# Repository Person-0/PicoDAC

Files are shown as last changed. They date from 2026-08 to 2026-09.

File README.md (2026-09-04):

# **PicoDAC**

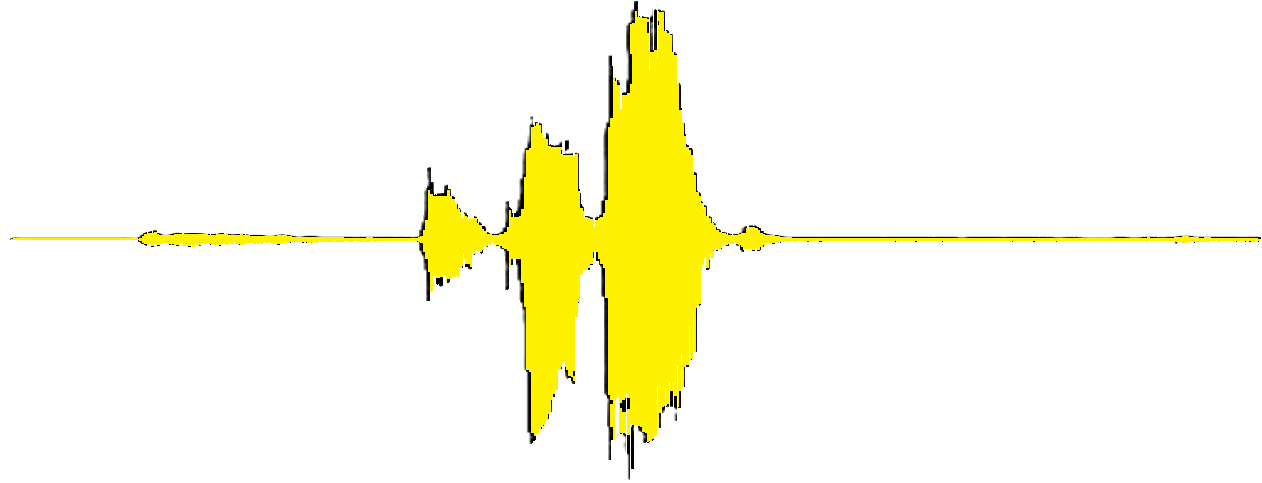
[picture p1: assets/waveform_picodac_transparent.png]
<br>

*USB-C to 3.5mm HiFi mini DAC*

Fully custom PCB and 3D printed case.

## Design

### Preview Images
Note that a specially cut transparent acrylic sheet will be used as the top lid of the main PCB case which will be superglued to part of the case that is non-detachable.

The main PCB case also requires [this 2.5X8 screw](https://sharvielectronics.com/product/m2-5x8mm-phillips-head-mounting-screw-stainless-steel/) that will be used to attach the detachable part with the non-detachable part.

As for the case of the board - 2, since it really is just two directly connected USB-C plugs, the top and bottom part of the case will be glued together after seating the board-2 PCB inside it properly (after testing it).

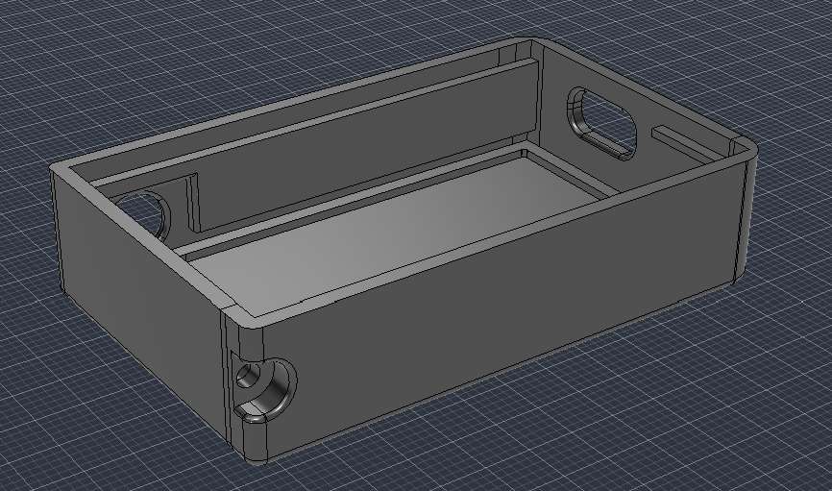
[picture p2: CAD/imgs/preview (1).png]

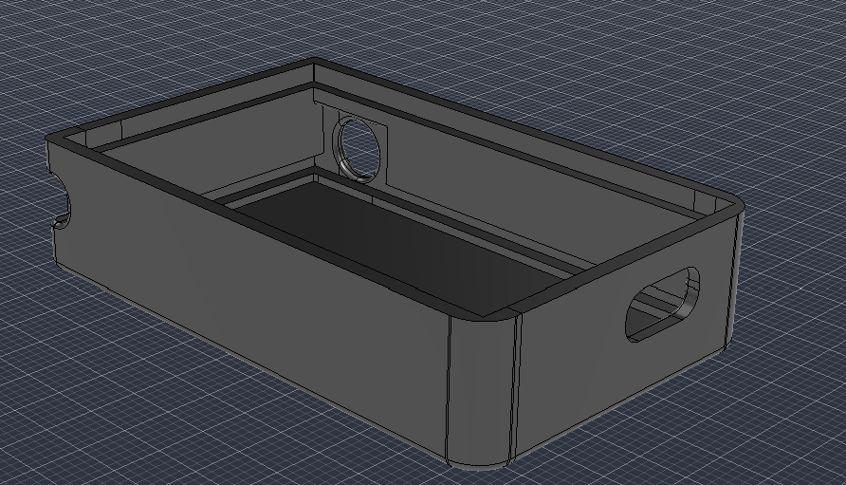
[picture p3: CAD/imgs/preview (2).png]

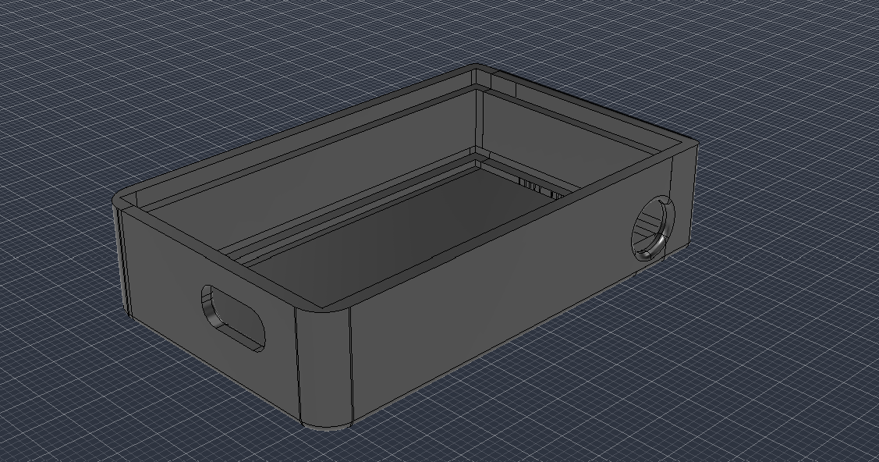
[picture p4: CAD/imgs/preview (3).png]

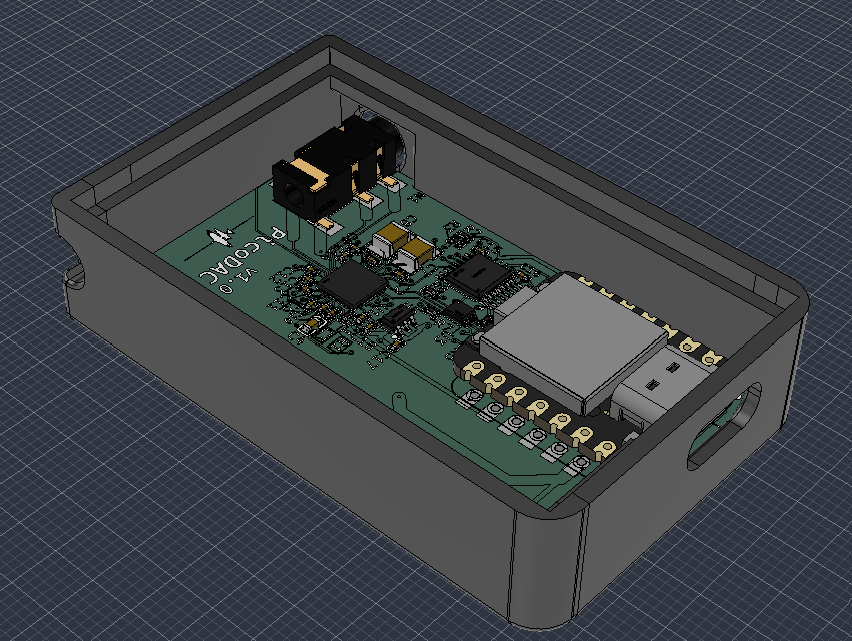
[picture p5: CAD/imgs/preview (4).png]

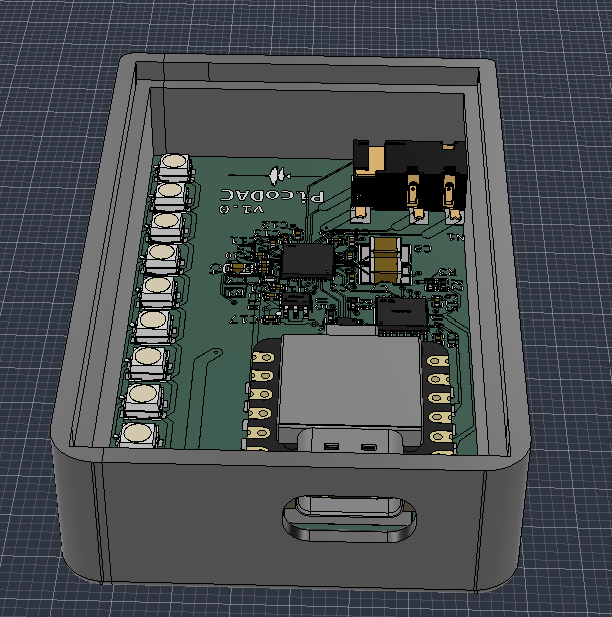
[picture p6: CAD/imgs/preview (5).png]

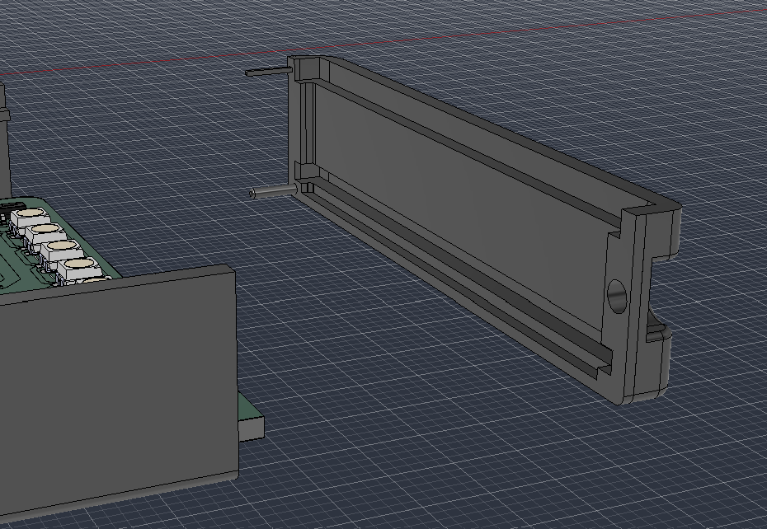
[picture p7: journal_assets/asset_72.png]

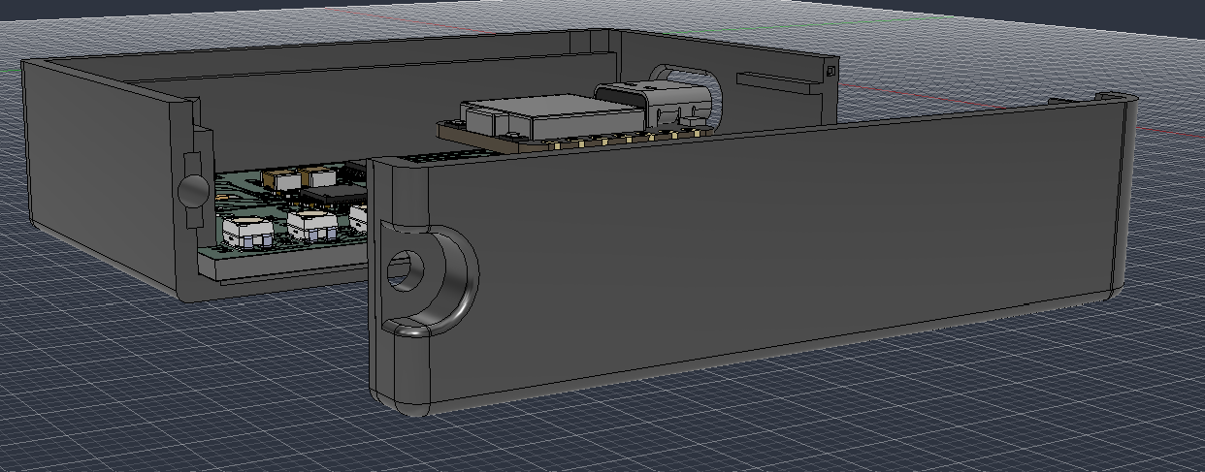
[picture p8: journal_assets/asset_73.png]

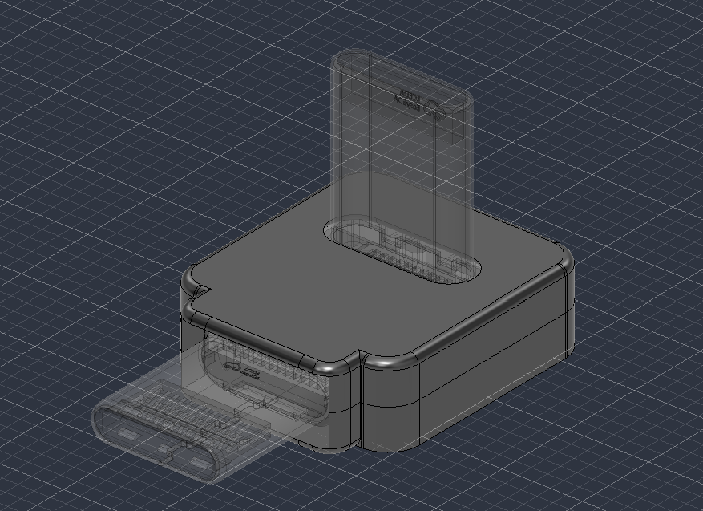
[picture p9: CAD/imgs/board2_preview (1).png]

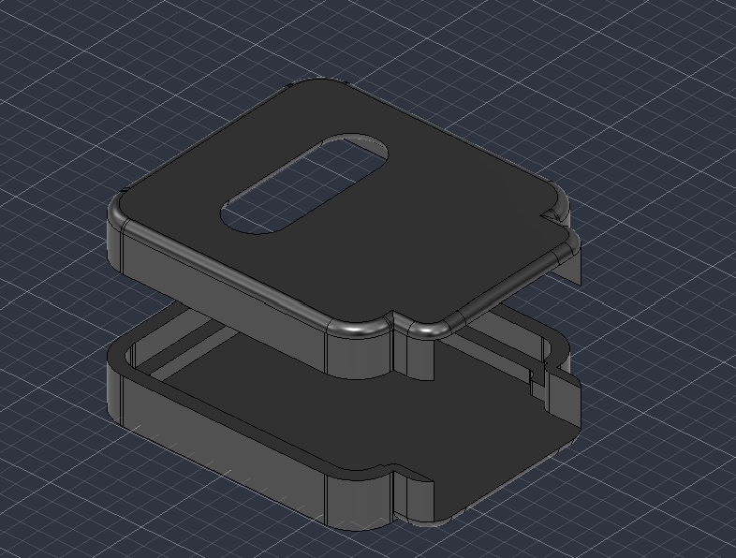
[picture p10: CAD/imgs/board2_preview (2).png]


<br>

All the design files are available in the [CAD folder](./CAD/).<br>
Exported STEP files for 3d-printing are available in [/CAD/exports](./CAD/exports/).

> Also note that the files:<br> 
> [1_PicoDAC_Case_DetachablePart.step](./CAD/exports/1_PicoDAC_Case_DetachablePart.step)<br>
> [2_PicoDAC_Case_Main.step](./CAD/exports/2_PicoDAC_Case_Main.step)<br>
> [3_board2_top_case.step](./CAD/exports/3_board2_top_case.step)<br>
> [4_board2_bottom_case.step](./CAD/exports/4_board2_bottom_case.step)<br>
> need to be printed as separate bodies.<br>
> All these files are also available in `.stl` format inside the [CAD/exports/stl_files](./CAD/exports/stl_files/) directory.

## **Motivation**

I recently bought a cheap USB-C to 3.5mm DAC and it was working perfectly fine until it broke.

I use my phone in bed a lot (yes i know this is a bad habit) vertically with the bottom of my phone resting on my chest. Since the USB-C port is at the bottom of my phone, anything connected to it has to do the heavy lifting of keeping the phone upright.

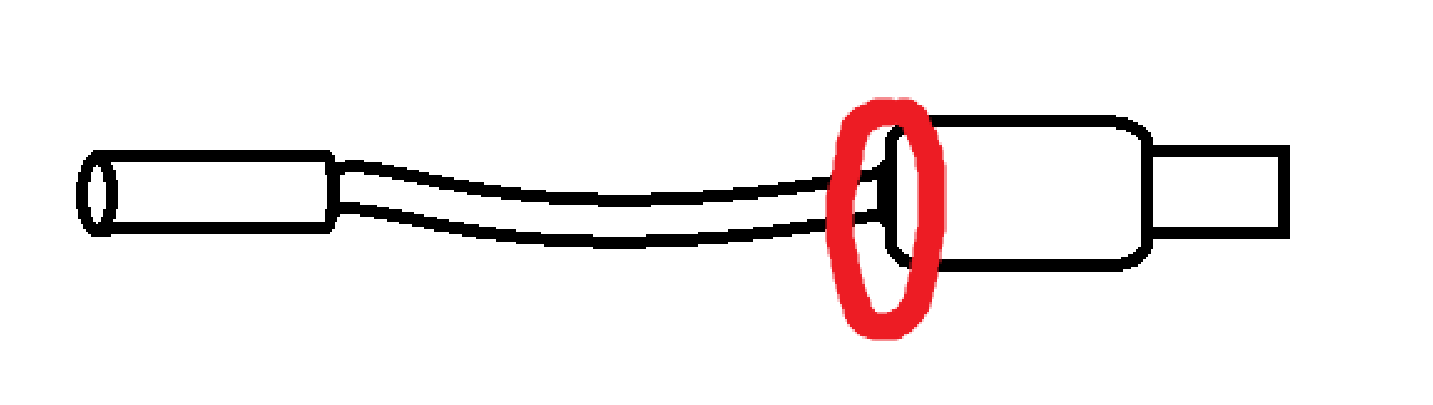
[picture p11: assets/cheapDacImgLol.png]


Naturally, the red part I've highlighted in the image slowly got bent and broke :(

To fix this issue, learn more about audio electronics, engineer a cool device and also make a higher-quality DAC in the process, I've started this project.

## **Hardware**
Main hardware components are:
- 1x CS43131-CNZR (A high-performance, 32-bit resolution, stereo audio DAC that supports up to 384-kHz sampling frequency with integrated low-noise ground-centered headphone amplifiers.): [LCSC part](https://www.lcsc.com/product-detail/C965907.html)
- XIAO RP2350 instead of the 2040 as it has integrated fractional dividers (also see: [this git issue](https://github.com/raspberrypi/pico-sdk/issues/1924))
- 9x SK6812 RGB LEDs for music level visualization

> **[View complete BOM](#bom)**

PCB Preview:

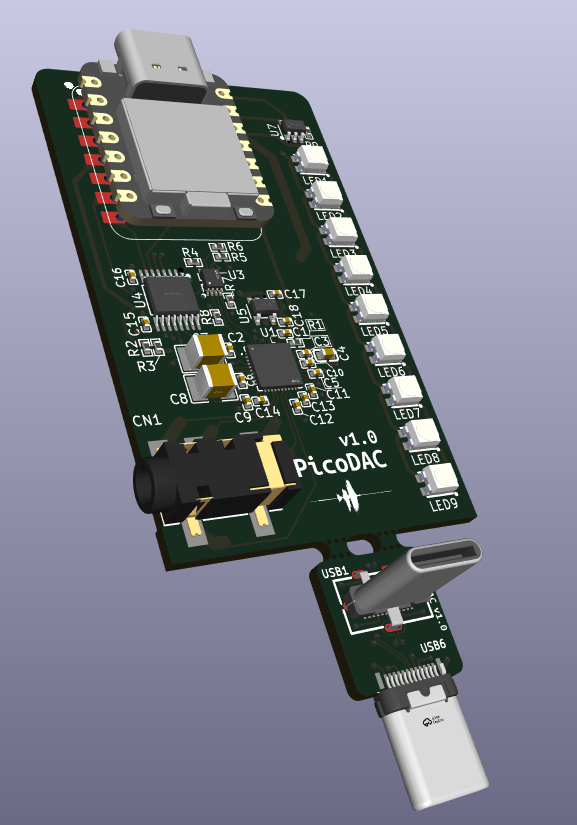
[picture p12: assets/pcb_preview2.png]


The complete schematics look like:

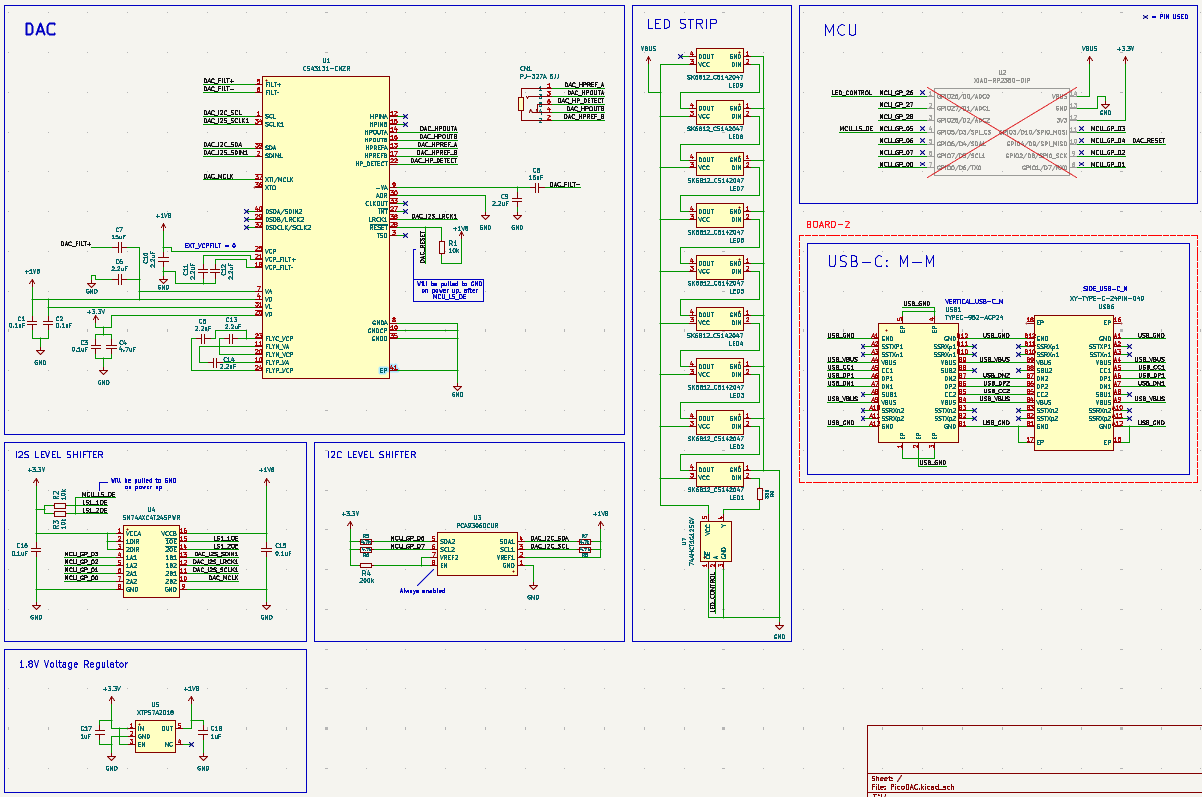
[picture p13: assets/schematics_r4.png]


**Main Board:**

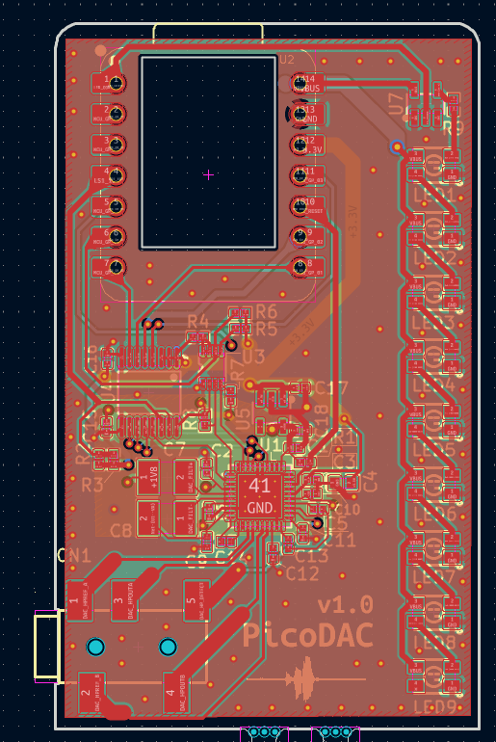
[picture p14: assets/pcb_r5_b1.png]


**Board 2:**

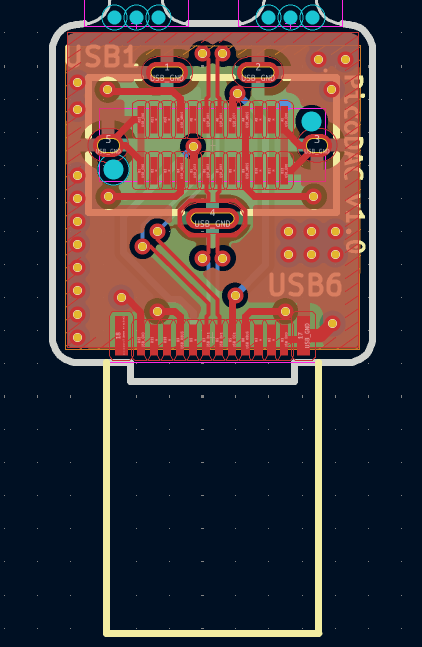
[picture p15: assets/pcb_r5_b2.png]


> Note that the PCB and schematic files can be opened using KiCAD. They are located in the `/hardware/PicoDAC` directory inside this repository.

Steps for viewing the PCB schematics and layout:
- Open KiCAD
- Click **File** (top left) >> **Open Project**
- Navigate to the the repository's saved destination,
- Open **/hardware/PicoDAC** directory
- Select the file `PicoDAC.kicad_pro`

## **Firmware**
*Checkout the [firmware directory](./firmware/) for the firmware README.md file and current status. It contains building, flashing instructions and also some special notes that might help with the process.*

## Ordering Parts, PCB/PCBA

I will be using JLCPCB along with their PCB Assembly service to get this PCB built assembled as it is the cheapest and best option available in my region.

Other than that, the only extra part is the **XIAO RP2350** MCU which is available on [robu.in](https://robu.in/).

> Note that the following PCB, PCBA costs are for 5 PCBs out of which 2 are assembled (this is the MOQ for JLCPCB) and also I have used basic components instead of extended wherever possible to reduce costs. 

### **BOM**
---

| S.No | Name | Description | Qty | Product URL | Effective Cost ($) |
| ---: | --- | --- | --: | --- | ---: |
| 1 | JLCPCB_PCB | PCB | 1 | ~ | 7.00 |
| 2 | JLCPCB_Assembly | PCB Assembly | 1 | ~ | 68.03 |
| 3 | JLCPCB_Shipping | Lowest price shipping: UPS Worldwide Express Saver | 1 | ~ | 9.10 |
| 4 | JLCPCB_Coupons | ~ | 1 | ~ | -10.00 |
| 5 | SeeedStudio XIAO RP2350 | MCU: XIAO RP2350 | 1 | [robu.in/...](https://robu.in/product/seeedstudio-xiao-rp2350-raspberry-pi-rp2350/) | 8.69 |
| 6 | Shipping for SeeedStudio XIAO RP2350 | Standard Shipping for XIAO RP2350 | 1 | ~ | 0.51 |
| 5 | Acrylic Lid for Main Case | Acrylic Laser Cutout (Qty = 2 as cost per piece is below 80INR and robu.in requires minimum cost to be atleast 80INR for non-metal laser cutting service order) | 2 | ~ | 1.63 |
| 6 | Shipping for Acrylic Lid | Standard Shipping for Acrylic Lid | 1 | ~ | 0.51 |
| | | | | **Total ($)** | **85.47** |
---

> The DXF file for the acrylic lid is available as [Main_Case_Lid_DoNotPrint.dxf](./CAD/exports/Main_Case_Lid_DoNotPrint.dxf) <br>
> Robu.in does not allow laser cutout service orders in the same cart as normal products, hence the two different 0.51$ shipping costs.

Please checkout the [/hardware/Ordering/](./hardware/Ordering/) directory to get the gerber, bom and cpl files to upload on JLC website.

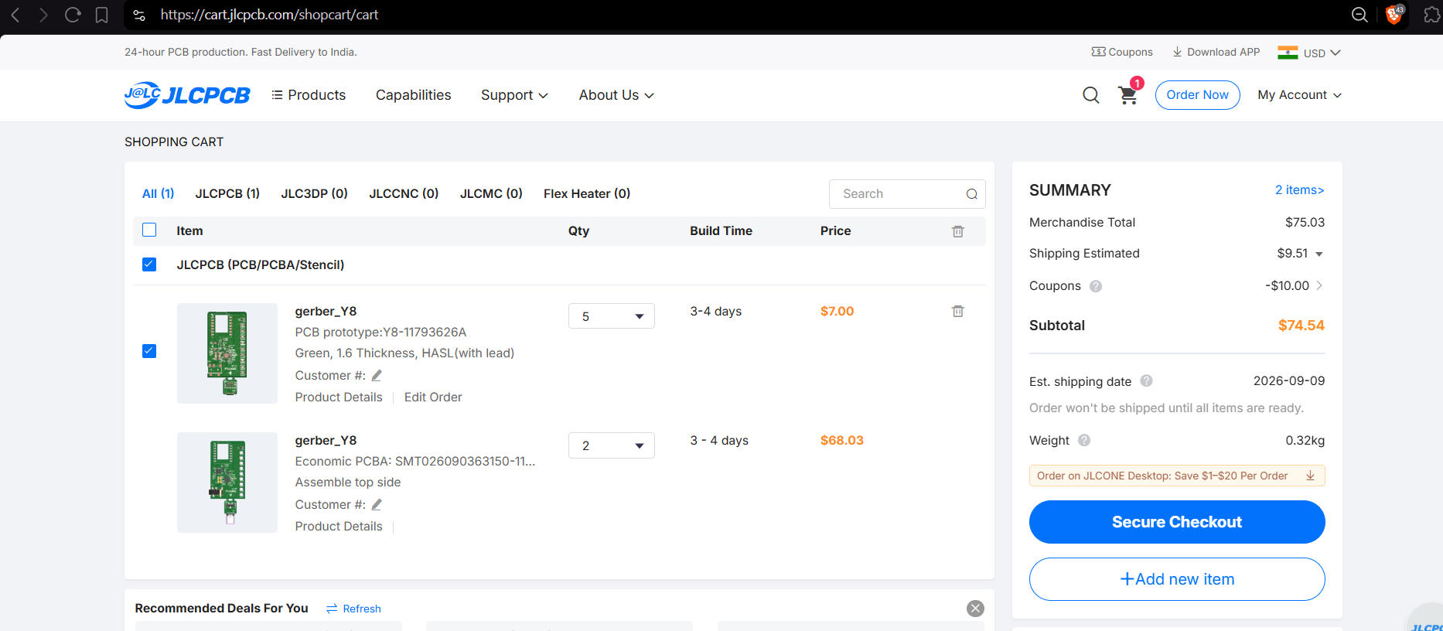
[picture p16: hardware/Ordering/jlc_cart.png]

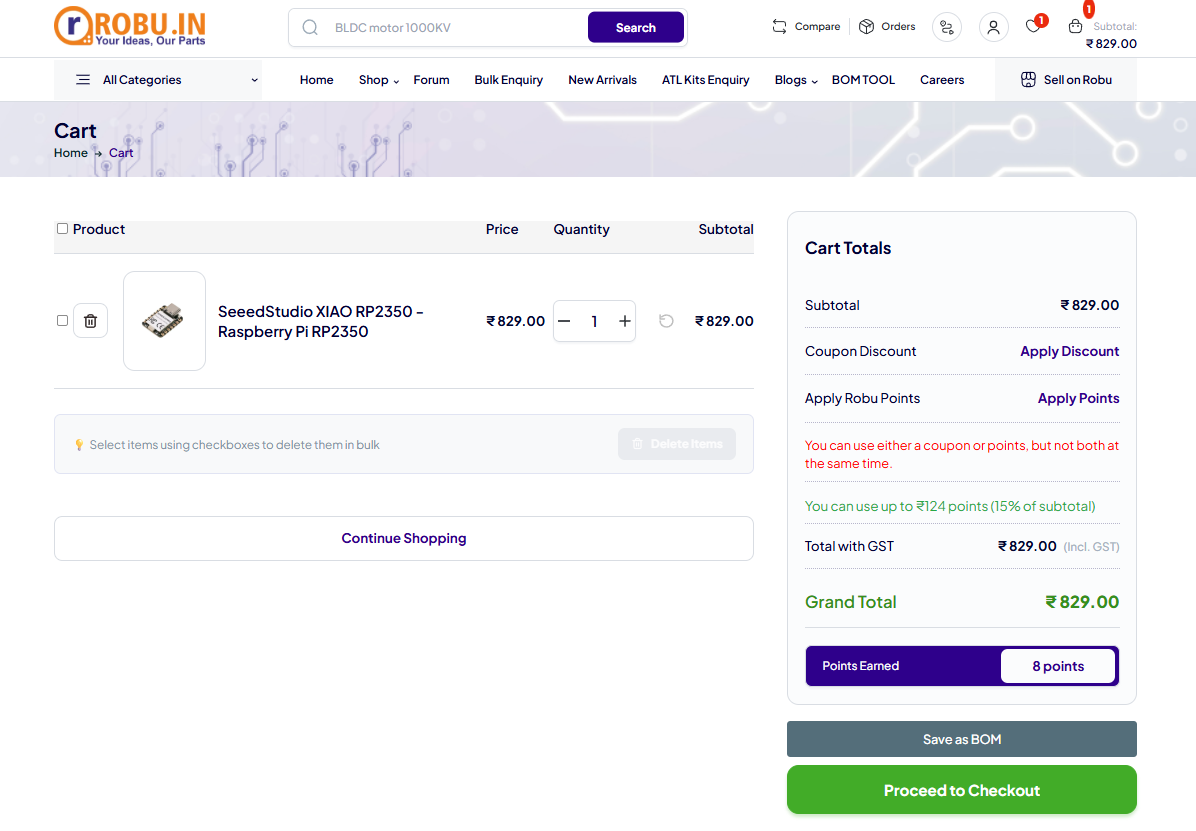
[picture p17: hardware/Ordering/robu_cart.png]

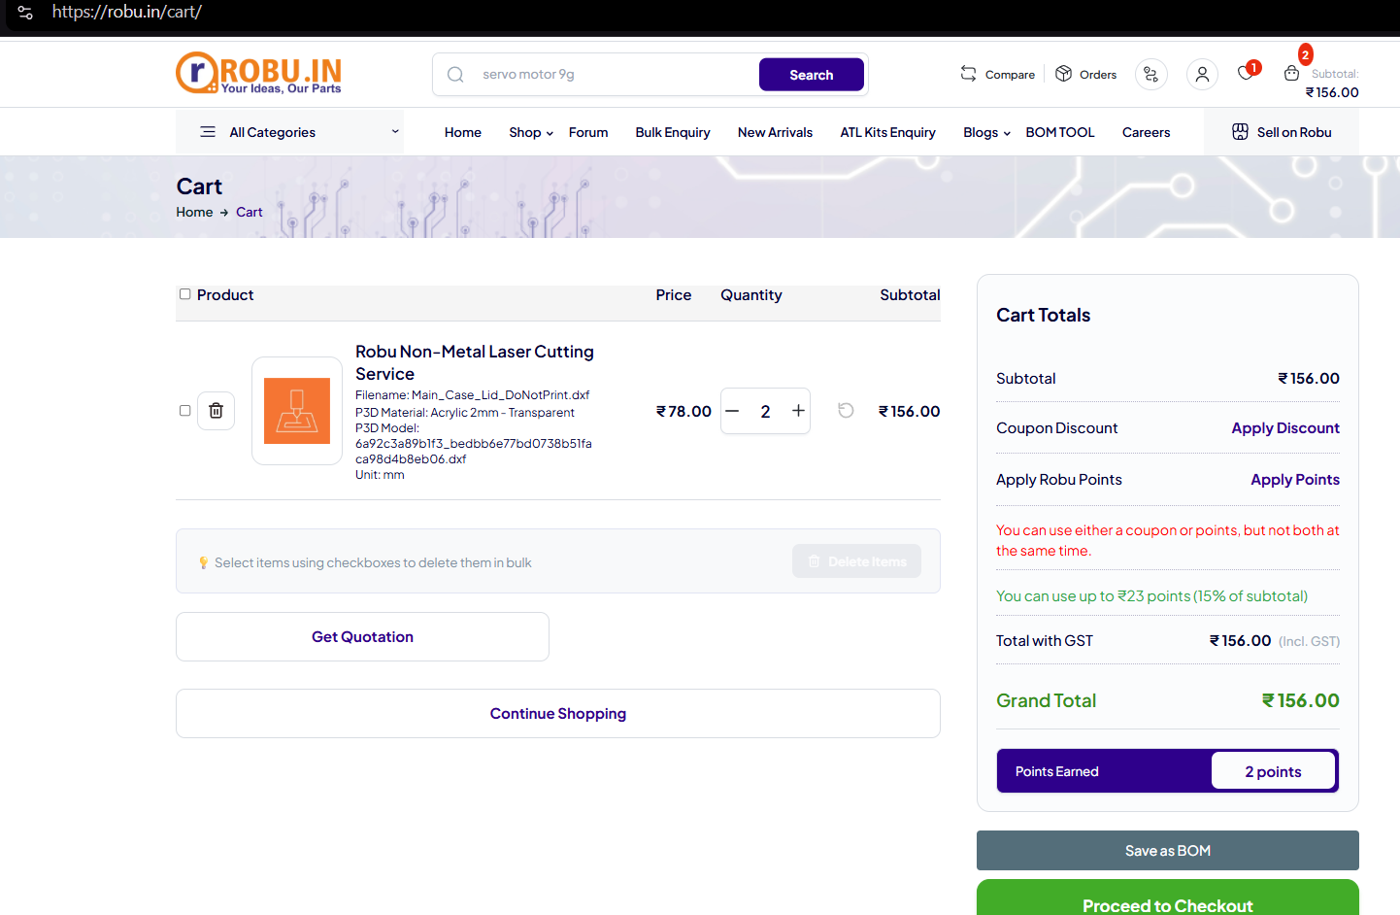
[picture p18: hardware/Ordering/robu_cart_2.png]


## **References**
- All datasheets in [**BOM.csv**](./hardware/Ordering/bom.csv)
- https://datasheets.raspberrypi.com/rp2350/rp2350-datasheet.pdf
- https://github.com/raspberrypi/pico-sdk/issues/1924
- https://electronics.stackexchange.com/questions/336836/understanding-audio-jack-connection
- https://electronics.stackexchange.com/questions/95575/how-does-the-phone-detect-if-3-5-mm-jack-circuit-is-closed
- https://www.lcsc.com/product-detail/C33196.html
- https://www.lcsc.com/product-detail/C2867798.html (english version: https://www.ti.com/lit/ds/symlink/sn74axc4t245.pdf)
- https://www.totalphase.com/blog/2024/07/what-are-i2c-pull-up-resistors-calculate-their-values/
- https://forum.arduino.cc/t/why-use-a-47k-resistor-between-3-3v-and-sda-and-scl-port-of-esp3266/850553
- https://files.seeedstudio.com/wiki/XIAO-RP2350/res/Seeed-Studio-XIAO-RP2350-v1.0.pdf
- https://www.alldatasheet.com/datasheet-pdf/pdf/1265214/TI/TPS7A201825PDQNR.html
- https://wiki.seeedstudio.com/xiao_rp2350_arduino/
- https://forum.kicad.info/t/how-to-create-teardrops-in-pcb-editor/61920/
- https://electronics.stackexchange.com/questions/686845/pcb-design-question-power-plane-or-fat-traces-for-high-current
- https://www.eevblog.com/forum/eda/should-plane-be-used-to-connect-power-or-just-thicker-tracks/

## 😼💖

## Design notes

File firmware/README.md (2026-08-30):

# PicoDAC Firmware

This directory contains the firmware for PicoDAC, based on the TinyUSB's [uac2_speaker_fb](https://github.com/hathach/tinyusb/tree/0.17.0/examples/device/uac2_speaker_fb) example (MIT License).

> Note that the board selected is `Pico 2` (non risc-v) but the actual board is XIAORP2350, which has an extra onboard Neopixel RGB LED that we are using to show the DAC state (checkout [src/dac.c](./src/dac.c)).

## Current State

Firmware is WIP and needs real-world testing, hence the current state is very basic.

Currently only these two things have been tested to work:

- Windows11 recognizes it as a USB Audio Class 2 Device
- Streaming audio makes the onboard LED as set in the Blink pattern enum in [PicoDAC.c](./PicoDAC.c)

The following stuff is untested and will be tested, fixed if required once I get my hands on the necessary components or/and the built PCB:
- Onboard Neopixel RGB LED
- DAC Initialization process

The following stuff will be implemented after the stuff mentioned above is done:
- DAC audio playback (ring buffer implementation?)
- 9x RGB LED strip (music level visualizer): Since it requires me to process the music data, i've decided to do it after the DAC accepts the USB audio data

## Current Startup sequence
1. Power On (everything is powered up, uses USB-C VBUS)
2. MCU's Onboard LED indicator blinks and shows USB status live accodingly
3. MCU's Onboard Neopixel indicator shows DAC init status **(untested)**
    - Blue = init
    - Green = DAC OK
    - Red = DAC init failed / error

## Firmware Compiling / Flashing
- Install the [Raspberry Pi Pico VS Code extension](https://marketplace.visualstudio.com/items?itemName=raspberry-pi.raspberry-pi-pico)
- Clone this repository
- Open this folder (/firmware) in VS Code
- The extension will automatically detect your workspace and install necessary toolchains that will be used to compile the firmware
- Edit files if required
- Press `Compile` at the bottom bar to test whether the firmware compiles successfully
- Hold the boot tactile switch on the XIAO-RP2350 while plugging it into your PC, this will allow us to flash the firmware
- Use the `Run` button next to the Compile button at the bottom bar to compile, flash the firmware to the Pico. After the firmware is flashed, the Pico will auto reboot and you will see the results directly.

## Special Notes

- Use the official Raspberry Pi Pico VS Code extension to build or flash the firmware as it will save you lots of time and config messes.
- (VERY IMPORTANT) If the device freezes on audio playback, downgrade the **TinyUSB** version from `0.18.0` (which comes bundled with `Pico SDK 2.3.0`) to `0.17.0`. Debugging this took me hours and this was the only fix I found that worked for me. See [this github issue](https://github.com/hathach/tinyusb/discussions/3215).

## Pin Reference
- GP00 - DAC_MCLK
- GP01 - DAC_SCLK1
- GP02 - DAC_LCRK1
- GP03 - DAC_SDIN1
- GP04 - DAC_RESET
- GP05 - MCU_LS_OE (level shifter output-enable)
- GP06 - DAC_SDA
- GP07 - DAC_SCL
<br>...
- GP22 - ONBOARD_NEOPIXEL
- GP23 - ONBOARD_NEOPIXEL_PWR
- GP25 - ONBOARD_LED
- GP26 - LED_CONTROL (9x SK6812 Row)

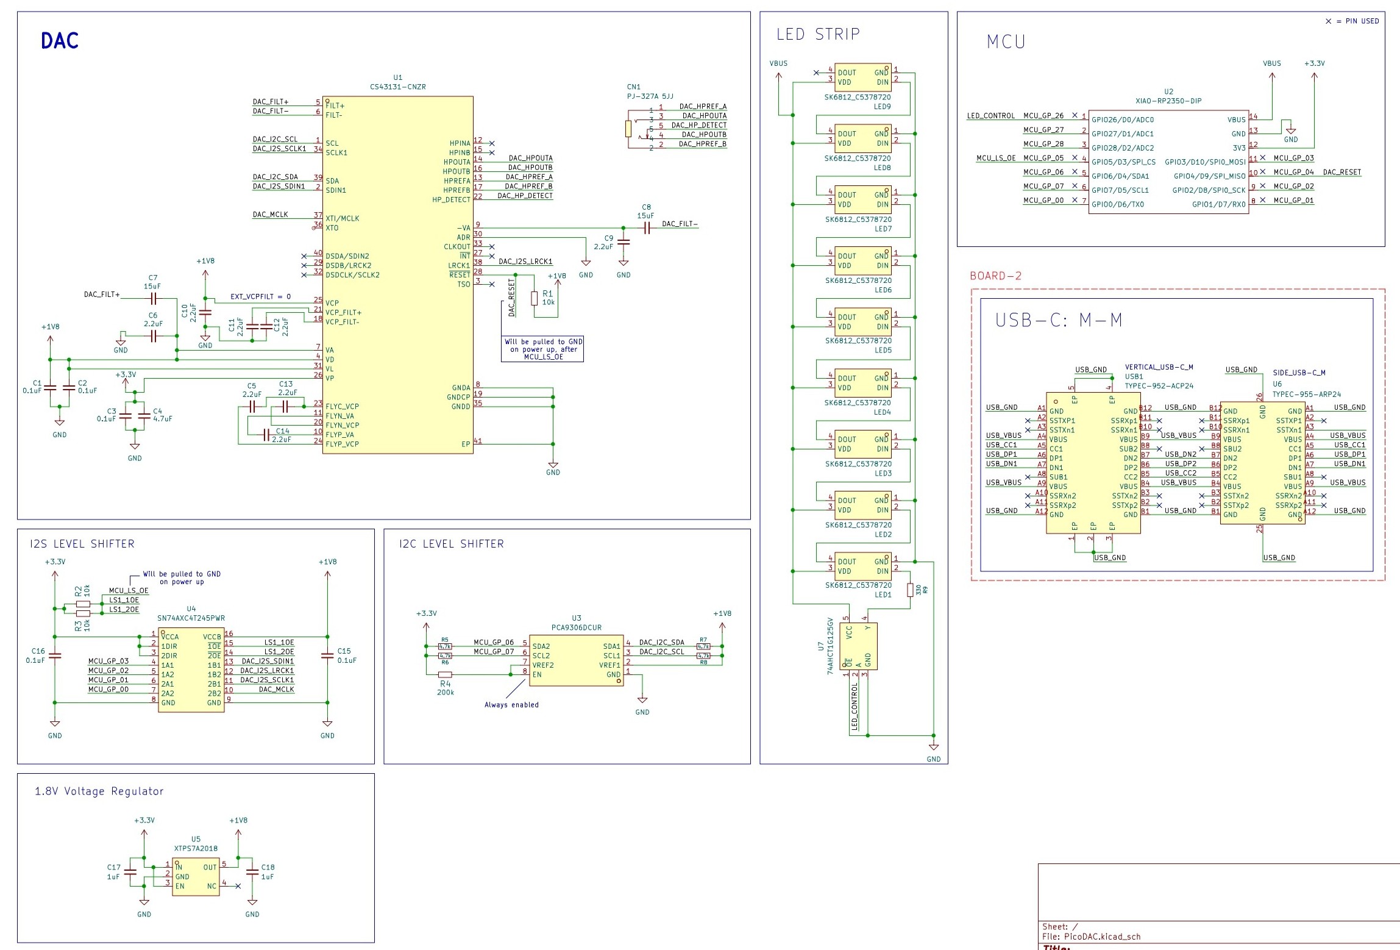
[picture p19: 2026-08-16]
assets/schematics_r3.jpg

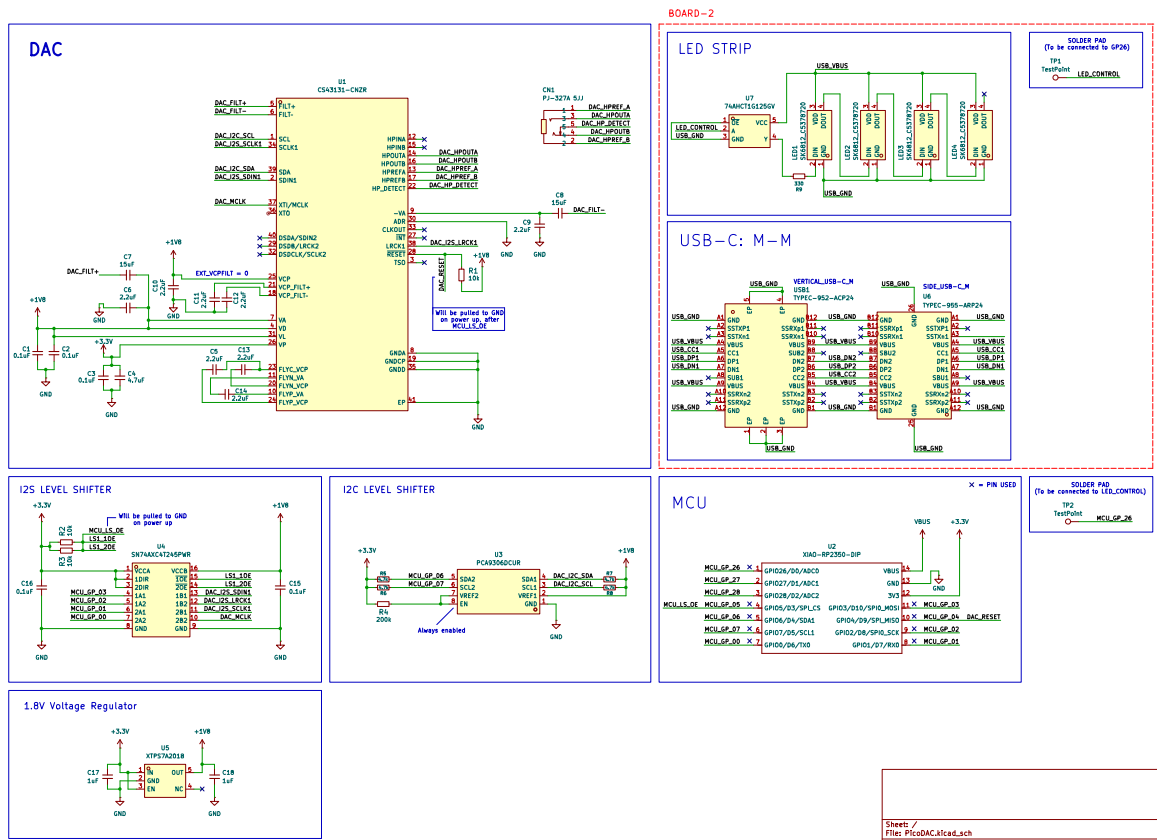
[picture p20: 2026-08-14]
assets/schematics_r2.png

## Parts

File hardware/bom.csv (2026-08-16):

Reference | Qty | Value | DNP | Exclude from BOM | Exclude from Board | Footprint | Datasheet | MPN | Manufacturer | LCSC Part | Description | #
C1,C2,C3,C15,C16 | 5 | 0.1uF |  |  |  | easyeda2kicad:C0402 | https://www.lcsc.com/datasheet/C60474.pdf | CC0402KRX7R7BB104 |  | C60474 | Unpolarized capacitor, small symbol | 1
C4 | 1 | 4.7uF |  |  |  | easyeda2kicad:C0603 | https://www.lcsc.com/datasheet/C19666.pdf | CL10A475KO8NNNC |  | C19666 | Unpolarized capacitor, small symbol | 2
C5,C6,C9,C10,C11,C12,C13,C14 | 8 | 2.2uF |  |  |  | easyeda2kicad:C0201 | https://www.lcsc.com/datasheet/C335106.pdf | GRM033R61A225KE47D |  | C335106 | Unpolarized capacitor, small symbol | 3
C7,C8 | 2 | 15uF |  |  |  | easyeda2kicad:C1210 | https://www.lcsc.com/datasheet/C694469.pdf | C3225X7R1C156MT000N |  | C694469 | Unpolarized capacitor, small symbol | 4
C17,C18 | 2 | 1uF |  |  |  | easyeda2kicad:C0402 | https://www.lcsc.com/datasheet/C52923.pdf | CL05A105KA5NQNC |  | C52923 | Unpolarized capacitor, small symbol | 5
CN1 | 1 | PJ-327A 5JJ |  |  |  | easyeda2kicad:AUDIO-SMD_PJ-327A5JJ | https://lcsc.com/product-detail/Audio-Video-Connectors_SHOU-HAN-PJ-327A-5JJ_C668605.html | PJ-327A 5JJ | SHOU HAN(首韩) | C668605 |  | 6
LED1,LED2,LED3,LED4,LED5,LED6,LED7,LED8,LED9 | 9 | SK6812_C5378720 |  |  |  | easyeda2kicad:LED-SMD_4P-L5.4-W5.0_SK6812 | https://www.lcsc.com/datasheet/C5378720.pdf | SK6812 | 欧思科光电 | C5378720 |  | 7
R1,R2,R3 | 3 | 10k |  |  |  | easyeda2kicad:R0402 | https://www.lcsc.com/datasheet/C60490.pdf | RC0402FR-0710KL |  | C60490 | Resistor, small symbol | 8
R4 | 1 | 200k |  |  |  | easyeda2kicad:R0402 | https://www.lcsc.com/datasheet/C25764.pdf | 0402WGF2003TCE |  | C25764 | Resistor, small symbol | 9
R5,R6,R7,R8 | 4 | 4.7k |  |  |  | easyeda2kicad:R0402 | https://www.lcsc.com/datasheet/C105871.pdf | RC0402FR-074K7L |  | C105871 | Resistor, small symbol | 10
R9 | 1 | 330 |  |  |  | easyeda2kicad:R0402 | https://www.lcsc.com/datasheet/C105875.pdf | RC0402FR-07330RL |  | C105875 | Resistor, small symbol | 11
U1 | 1 | CS43131-CNZR |  |  |  | easyeda2kicad:TQFN-40_L5.0-W5.0-P0.40-TL-EP3.5 | https://www.lcsc.com/datasheet/C965907.pdf | CS43131-CNZR | Cirrus Logic(凌云) | C965907 |  | 12
U2 | 1 | XIAO-RP2350-DIP |  | Excluded from BOM |  | Seeed Studio XIAO Series Library:XIAO-RP2350-DIP |  |  |  |  |  | 13
U3 | 1 | PCA9306DCUR |  |  |  | easyeda2kicad:SSOP-8_L2.0-W2.3-P0.50-LS3.1-BR | https://lcsc.com/product-detail/Interface-ICs_TI_PCA9306DCUR_PCA9306DCUR_C33196.html | PCA9306DCUR | TI(德州仪器) | C33196 |  | 14
U4 | 1 | SN74AXC4T245PWR |  |  |  | easyeda2kicad:TSSOP-16_L5.0-W4.4-P0.65-LS6.4-BL | https://www.lcsc.com/datasheet/C2867798.pdf | SN74AXC4T245PWR | TI(德州仪器) | C2867798 |  | 15
U5 | 1 | XTPS7A2018 |  |  |  | easyeda2kicad:SOT-23-5_L3.0-W1.7-P0.95-LS2.8-BL | https://www.lcsc.com/datasheet/C51953293.pdf | XTPS7A2018-XC | SiChange(芯昌科技) | C51953293 |  | 16
U6 | 1 | TYPEC-955-ARP24 |  |  |  | easyeda2kicad:USB-C-SMD_TYPE-C-24P-GTJB-040 | https://www.lcsc.com/datasheet/C3151751.pdf | TYPE-C 24P-GTJB 040 | SHOU HAN(首韩) | C3151751 |  | 17
U7 | 1 | 74AHCT1G125GV |  |  |  | easyeda2kicad:SOT-23-5_L3.0-W1.7-P0.95-LS2.8-BL | https://www.lcsc.com/datasheet/C52140417.pdf | 74AHCT1G125GV | MDD(辰达半导体) | C52140417 |  | 18
USB1 | 1 | TYPEC-952-ACP24 |  |  |  | easyeda2kicad:USB-C-SMD_TYPEC-952-ACP24 | https://www.lcsc.com/datasheet/C2840398.pdf | TYPEC-952-ACP24 | XUNPU(讯普) | C2840398 |  | 19

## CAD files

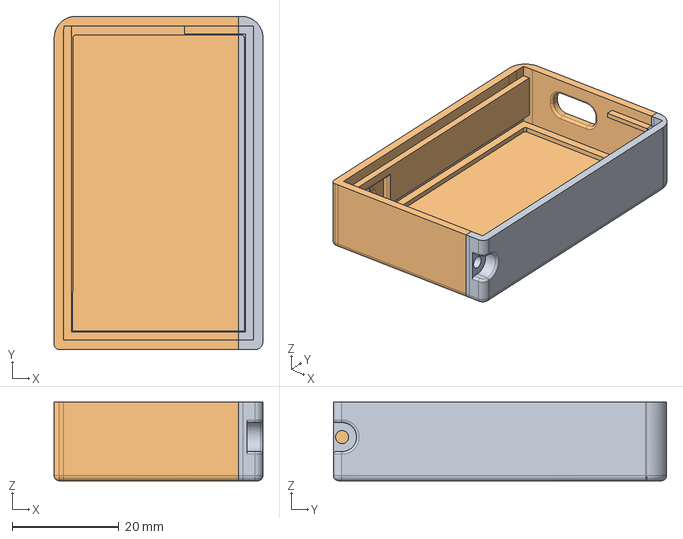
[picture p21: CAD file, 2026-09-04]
CAD/exports/Main_Case_DoNotPrint.step
39.1 x 62.3 x 14.7 mm

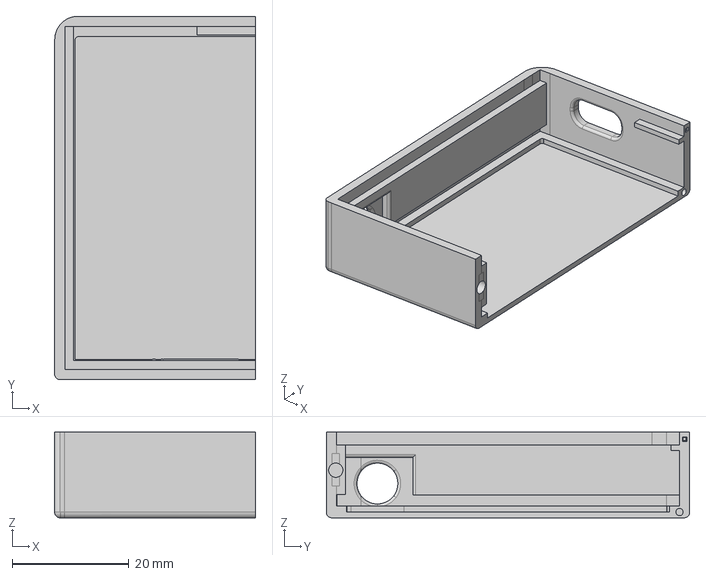
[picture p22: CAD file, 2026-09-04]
CAD/exports/prints/2_PicoDAC_Case_Main.step
34.5 x 62.3 x 14.7 mm

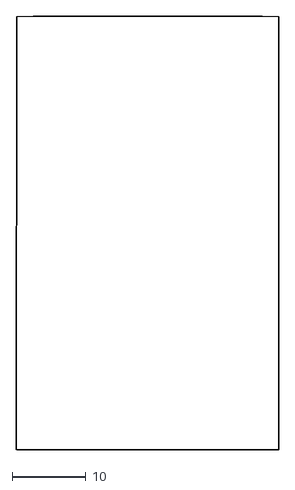
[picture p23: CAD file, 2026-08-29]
CAD/exports/Main_Case_Lid_DoNotPrint.dxf
35.6 x 58.8

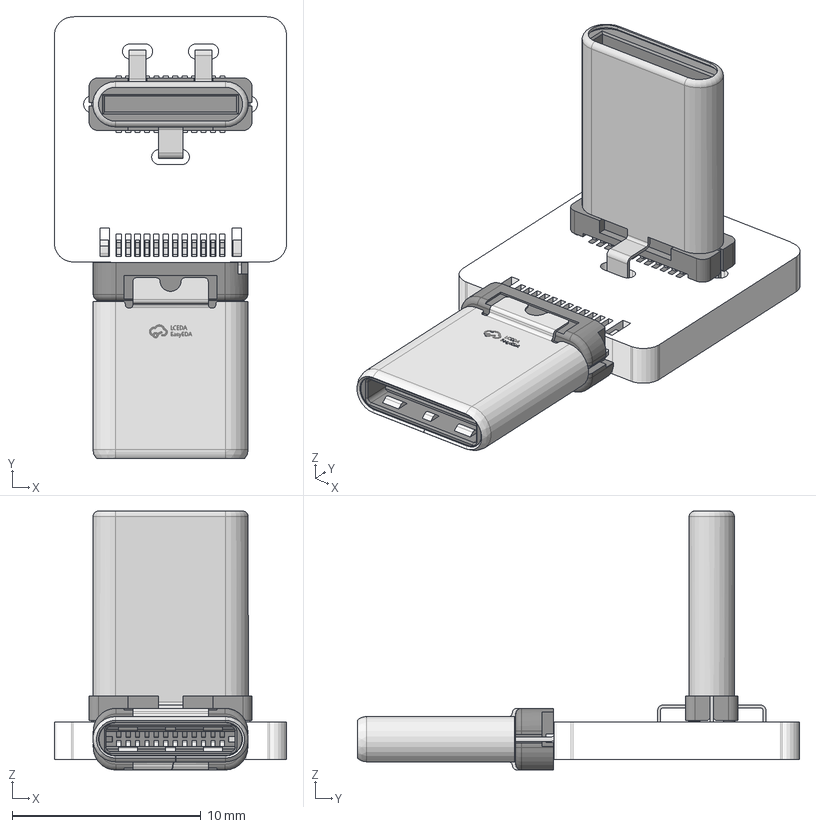
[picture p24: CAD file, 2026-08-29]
CAD/models/PicoDAC_board2_PCB.step
12.3 x 23.5 x 13.7 mm
PicoDAC_PCB
PicoDAC_soldermask
PicoDAC_soldermask_1
PicoDAC_pad
PicoDAC_silkscreen
USB-C-SMD_XY-TYPE-C-24PIN-040
USB-C-SMD_TYPEC-952-ACP24

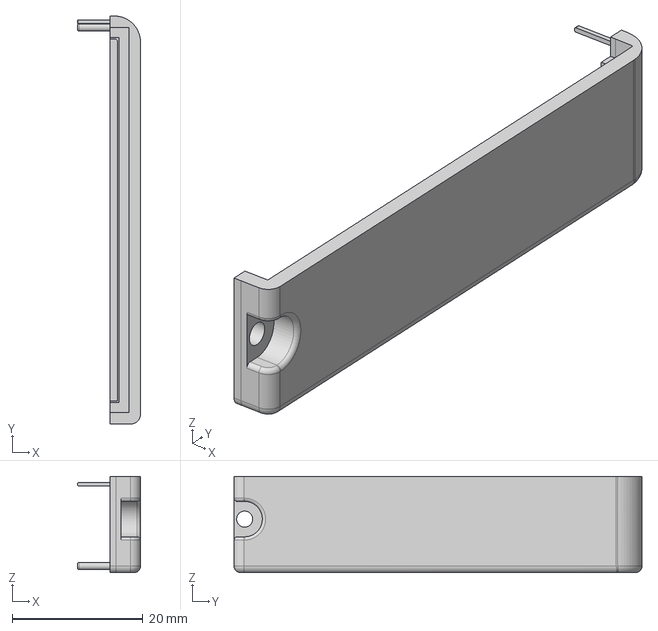
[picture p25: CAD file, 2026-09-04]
CAD/exports/prints/1_PicoDAC_Case_DetachablePart.step
9.63 x 62.3 x 14.7 mm

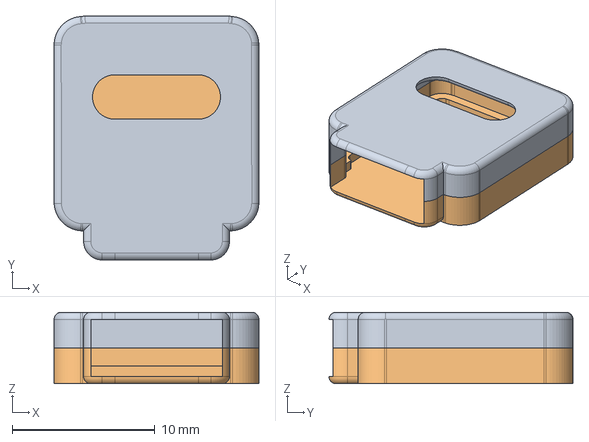
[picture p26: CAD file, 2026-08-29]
CAD/exports/board2_case_DoNotPrint.step
14.3 x 17.1 x 5.00 mm

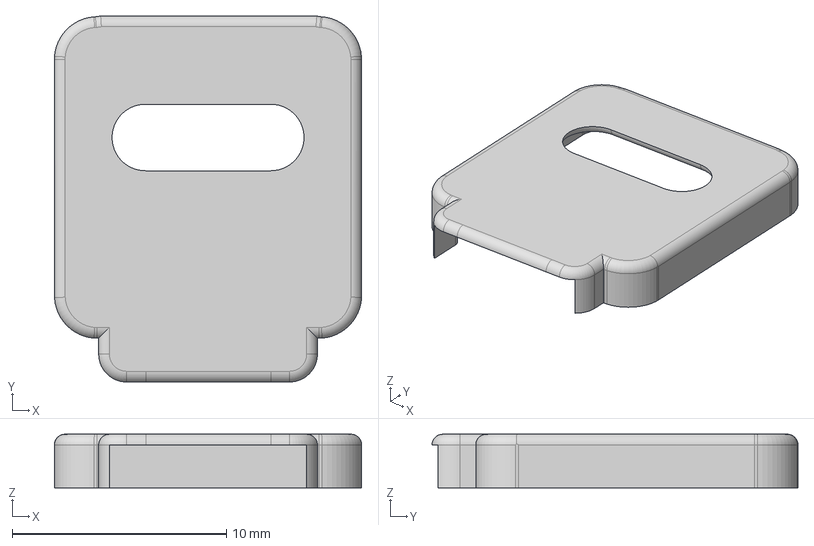
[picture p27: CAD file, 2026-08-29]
CAD/exports/prints/3_board2_top_case.step
14.3 x 17.1 x 2.50 mm

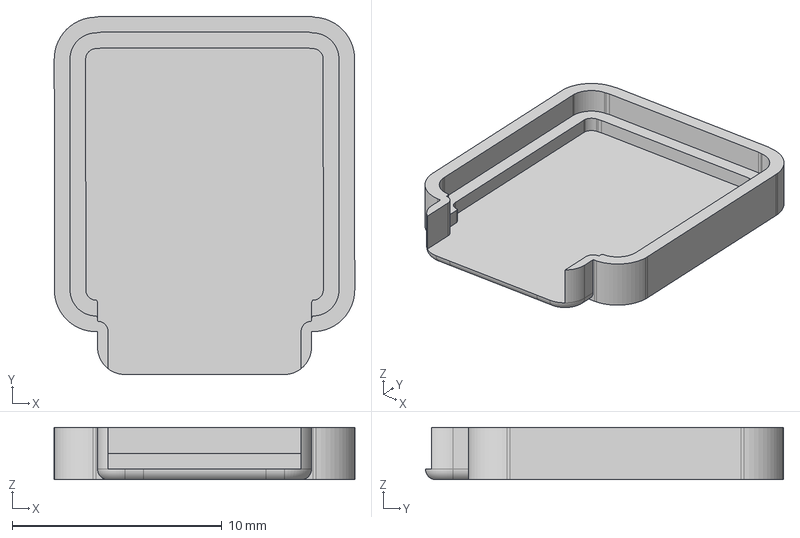
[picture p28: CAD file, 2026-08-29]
CAD/exports/prints/4_board2_bottom_case.step
14.3 x 17.1 x 2.50 mm

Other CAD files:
CAD/PicoDAC_Case_Main.f3z
CAD/PicoDAC_board2_case.f3d
CAD/exports/stl_files/1_PicoDAC_Case_DetachablePart.stl
CAD/exports/stl_files/2_PicoDAC_Case_Main.stl
CAD/exports/stl_files/3_board2_top_case.stl
CAD/exports/stl_files/4_board2_bottom_case.stl

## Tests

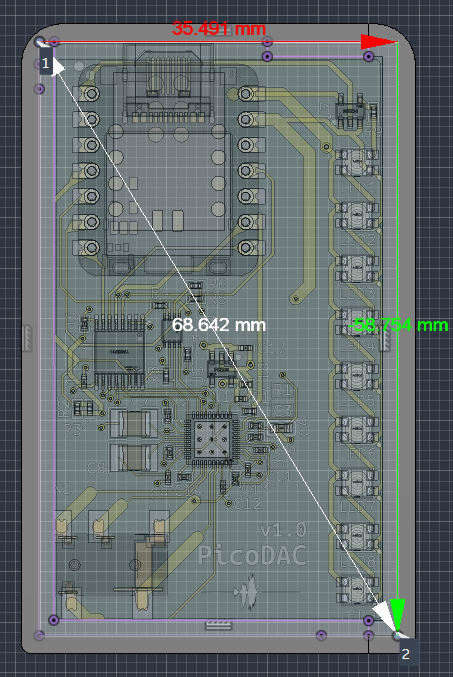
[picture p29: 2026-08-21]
CAD/imgs/acrylicSheetMeasurement.png

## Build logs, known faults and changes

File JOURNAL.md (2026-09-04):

---
title: "PicoDAC"
author: "Person-0"
description: "USB-C to 3.5mm HiFi mini DAC"
created_at: "2026-08-03"
---

# 2026-09-04: CAD update

I removed the big friction fit slot and extrusion in the main board case with a hole for screwing in [this 2.5X8 screw](https://sharvielectronics.com/product/m2-5x8mm-phillips-head-mounting-screw-stainless-steel/), which will help hold the case together better.

The main board case now looks like this:





# 2026-09-03: Ground fill, Stitching Vias
I added ground fill for both top and bottom layers as I had not done that before.

The updated PCB look like this:





I exported the new gerber zip file and now the BOM looks like this:

| S.No | Name | Description | Qty | Product URL | Effective Cost ($) |
| ---: | --- | --- | --: | --- | ---: |
| 1 | JLCPCB_PCB | PCB | 1 | ~ | 7.00 |
| 2 | JLCPCB_Assembly | PCB Assembly | 1 | ~ | 68.03 |
| 3 | JLCPCB_Shipping | Lowest price shipping: UPS Worldwide Express Saver | 1 | ~ | 9.10 |
| 4 | JLCPCB_Coupons | ~ | 1 | ~ | -10.00 |
| 5 | SeeedStudio XIAO RP2350 | MCU: XIAO RP2350 | 1 | [robu.in/...](https://robu.in/product/seeedstudio-xiao-rp2350-raspberry-pi-rp2350/) | 8.69 |
| 6 | Shipping for SeeedStudio XIAO RP2350 | Standard Shipping for XIAO RP2350 | 1 | ~ | 0.51 |
| 5 | Acrylic Lid for Main Case | Acrylic Laser Cutout (Qty = 2 as cost per piece is below 80INR and robu.in requires minimum cost to be atleast 80INR for non-metal laser cutting service order) | 2 | ~ | 1.63 |
| 6 | Shipping for Acrylic Lid | Standard Shipping for Acrylic Lid | 1 | ~ | 0.51 |
| | | | | **Total ($)** | **85.47** |

# 2026-08-29: board-2 case, bom update
## Board - 2 Case

I finished the case for board - 2 as mentioned in the previous journal. It looks like this:





The top and bottom are separate parts that need to be printed separately and after testing the Board-2 PCB and seating it inside the bottom part, the top part will be directly glued onto the bottom part.

I did not add extrusions for friction fitting or anything since this is a really small case (~1.5cm diagonally) and thin extrusions would just break. Also board-2 is really just two USB-C male plugs connected to each other directly, so this should be fine.

## BOM Update

In the previous BOM I did not mention the costs for the acrylic laser cutout for the Main case's lid so here it is in the updated BOM:

| S.No | Name | Description | Qty | Product URL | Effective Cost ($) |
| ---: | --- | --- | --: | --- | ---: |
| 1 | JLCPCB_PCB | PCB | 1 | ~ | 7.00 |
| 2 | JLCPCB_Assembly | PCB Assembly | 1 | ~ | 68.88 |
| 3 | JLCPCB_Shipping | Lowest price shipping: UPS Worldwide Express Saver | 1 | ~ | 9.10 |
| 4 | JLCPCB_Coupons | ~ | 1 | ~ | -10.00 |
| 5 | SeeedStudio XIAO RP2350 | MCU: XIAO RP2350 | 1 | [robu.in/...](https://robu.in/product/seeedstudio-xiao-rp2350-raspberry-pi-rp2350/) | 8.69 |
| 6 | Shipping for SeeedStudio XIAO RP2350 | Standard Shipping for XIAO RP2350 | 1 | ~ | 0.51 |
| 5 | Acrylic Lid for Main Case | Acrylic Laser Cutout (Qty = 2 as cost per piece is below 80INR and robu.in requires minimum cost to be atleast 80INR for non-metal laser cutting service order) | 2 | ~ | 1.63 |
| 6 | Shipping for Acrylic Lid | Standard Shipping for Acrylic Lid | 1 | ~ | 0.51 |
| | | | | **Total ($)** | **86.32** |



Robu.in does not allow laser cutout service orders in the same cart as normal products, hence the two different 0.51$ shipping costs (standard cheapest shipping is 49INR).

The PCBA BOM and CPL/Gerber files are available in the GitHub repository, under `hardware/Ordering` directory.

## Complete!

This was the last journal before review as also mentioned in the previous journal.

The firmware part is done in a basic way, all the cases have been designed and the PCB is complete.

Now all that left is to order the PCB, components and make the firmware work properly after extensive testing.

## **Thank you for reading my journal, Good luck!**
<br>

**Total time spent: 2 hours**

# 2026-08-29: Firmware current state, bom stuff
I finished basic firmware stuff for the project and the following is what is done and what isn't.

## Current Firmware State

Firmware is WIP and needs real-world testing, hence the current state is very basic.

Currently only these two things have been tested to work:

- Windows11 recognizes it as a USB Audio Class 2 Device
- Streaming audio makes the onboard LED as set in the Blink pattern enum in [PicoDAC.c](./PicoDAC.c)

The following stuff is **implemented but untested** and will be tested, fixed if required **once I get my hands on the necessary components or/and the built PCB**:
- Onboard Neopixel RGB LED working
- DAC Initialization process

The following stuff will be implemented after the stuff mentioned above is done:
- DAC audio playback (ring buffer implementation?): Requires the initialization step to work correctly. Without ensuring that the DAC initializes and the register read/writes happen properly, implementing this would be a dumb idea and possibly a waste of time.
- 9x RGB LED strip (music level visualizer): Since it requires me to process the music data, I've decided to do it after the DAC accepts the USB audio data first.

## Current Startup sequence
1. Power On (everything is powered up, uses USB-C VBUS)
2. MCU's Onboard LED indicator blinks and shows USB status live accodingly
3. MCU's Onboard Neopixel indicator shows DAC init status **(untested)**
    - Blue = init
    - Green = DAC OK
    - Red = DAC init failed / error

## JLC Ordering
I optimized the BOM to use basic parts wherever possible (changed some capacitor and resistor part numbers in the BOM while ensuring the specs remain the same). 

I added in the GitHub repository, a Ordering subdirectory inside the Hardware directory which contains the bom, cpl and gerber zip files so anyone can order the PCB/PCBA.

I also finalized the BOM (it is in the github readme at the bottom) with total cost of the PCB, PCB Assembly and extra components.

Cart Screenshots:

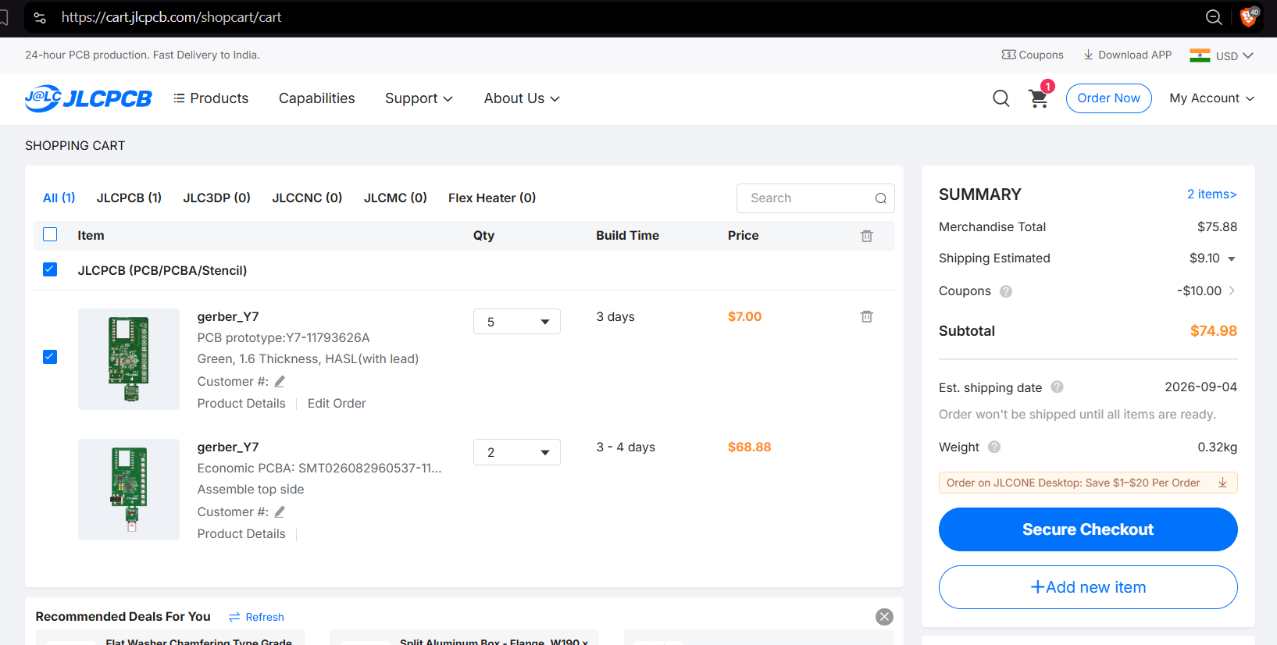
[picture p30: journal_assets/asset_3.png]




BOM Table:

| S.No | Name | Description | Qty | Product URL | Effective Cost ($) |
| ---: | --- | --- | --: | --- | ---: |
| 1 | JLCPCB_PCB | PCB | 1 | ~ | 7.00 |
| 2 | JLCPCB_Assembly | PCB Assembly | 1 | ~ | 68.88 |
| 3 | JLCPCB_Shipping | Lowest price shipping: UPS Worldwide Express Saver | 1 | ~ | 9.10 |
| 4 | JLCPCB_Coupons | ~ | 1 | ~ | -10.00 |
| 5 | SeeedStudio XIAO RP2350 | MCU: XIAO RP2350 | 1 | [robu.in/...](https://robu.in/product/seeedstudio-xiao-rp2350-raspberry-pi-rp2350/) | 8.69 |
| 6 | Shipping for SeeedStudio XIAO RP2350 | Shipping for XIAO RP2350 | 1 | ~ | 0.51 |
| | | | | **Total ($)** | **84.18** |

## Next Steps

Next I will be designing the case for Board-2 (USB-C M-M adapter board) which is the finish line to submit this project for review.
<br>

**Total time spent: 0.5 hours**

# 2026-08-29: i am losing my mind
## Firmware progress 🥹🥹

So in the last journal I mentioned I got Windows to recognize my Pico as an audio class device using the tinyusb's uac2_speaker example.

However, I found out that while it did get recognized as an audio class device, actually playing any audio after connecting the device to my PC made:
- windows explorer crash for a bit (it did restart and worked fine after a bit automatically)
- volume slider in windows would randomly change it's values (would go up/down randomly) while the device was connected
- pico board crash as soon as audio playback started
    - I tested and confirmed this using the Pico's onboard LED. I patched the LED code such that it blinked simultaneously within intervals of 100ms and as soon as audio playback started, the LED would freeze in the exact last state that it was in, which indicated that the Pico had crashed or reset (I know this behavior from past experiences with the Pico)

While I did confirm that the Pico was crashing/resetting, I seriously had NO idea whatsoever about what was causing it so I tried
- changing my USB cable
- using a different Pico board (XIAORP2040 as it has USB-C instead of micro usb that I got from the hackpad)
- disabling/enabling audio debug tasks
- reviewing the LED code again and again to confirm whether it was actually resetting or the LED code had some bug (it did not xd)

This took my around 3 hours of serious brainpower use and then I found out that some people also experienced the same issue with this exact PicoSDK + TinyUSB version. [Here is this GitHub issue](https://github.com/hathach/tinyusb/discussions/3215).

So, as mentioned in the issue, I tried downgrading TinyUSB from version `0.18.0` to `0.17.0` while keeping the PicoSDK version same and guess what.. It worked.

This marks the end of my journey to get USB audio working on the MCU and the next steps would be cleaning up the current messy codebase and then doing my best implementation of the firmware required for the DAC IC.

## ***Thank you for reading my journal, this one made me lose my mind.***

I've added a separate readme file in the firmware directory inside the GitHub repository where I have mentioned this issue and the solution to it so that anyone following along does not waste as much time as I did.

PicoDAC USB Device is no longer glitchy! Here is a bonus image of discord recognizing PicoDAC as a USB audio device!!!! (wohooo)

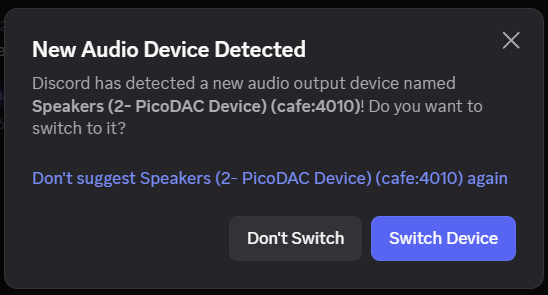
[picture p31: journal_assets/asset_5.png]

<br>

**Total time spent: 0 hours**

# 2026-08-22: firmware
## PicoDAC Firmware

I researched about USB audio, how it works and what are the requirements to get it working on a RPI PICO board.

Since I currently possess a PICO 1 devboard, I made the firmware run on that for now just to test the USB functionality (whether windows recognizes the device as an audio device, sends audio data and stuff)

This was a grueling task but after like 4 locked-in hours I finally got it to work. Current source is almost an identical copy of the [`uac2_speaker_fb` example](https://github.com/hathach/tinyusb/tree/master/examples/device/uac2_speaker_fb/) in the [TinyUSB github repository](https://github.com/hathach/tinyusb), but instead of a common `bsp/board_api.h` we are using `pico/stdlib.h` along with some more modifications, which were required for the example to work properly.

Windows recognizes the Pico as an audio device with the name PicoDAC Device:

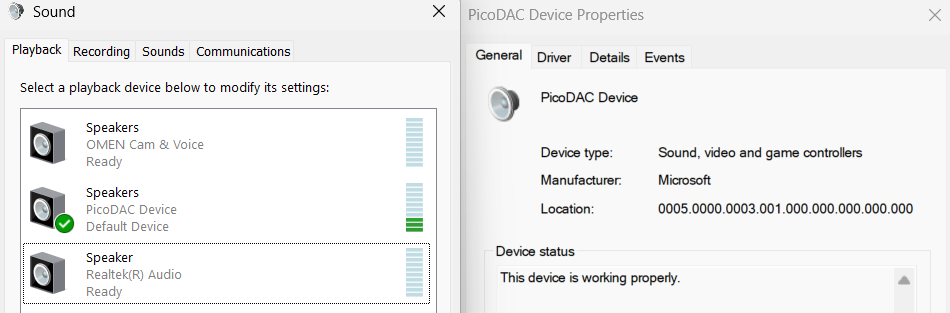
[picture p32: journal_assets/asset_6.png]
 

The firmware source is available in the GitHub repository.
<br>

**Total time spent: 0 hours**

# 2026-08-21: PCB Rev 1.5 + Main Case
### **Buckle up, deadline is near!!!!**

In this journal I describe how I made the case for the main board, what problems I encountered while doing so and how I fixed them. In-case I've missed any preview image or you need a reference, feel free to checkout the GitHub repository as it has all the necessary files related to the CAD or PCB.

*Fusion360 crashed 11 times during my quest to make the Main Board Case 💖*

## PCB Rev 1.5

When I made the first basic iteration of the enclosure, I found out that the 3.5mm audio jack on my PCB was placed incorrectly (as in not at the edge).

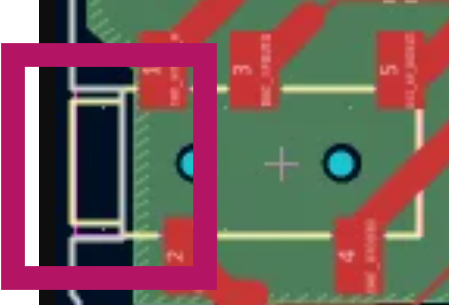
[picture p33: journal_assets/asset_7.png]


As we can see, the Edge.Cuts pcb edge actually needs to be connected in a straight line directly to the Edge.Cuts line defined in the audio jack footprint.

What I mean by that is this:

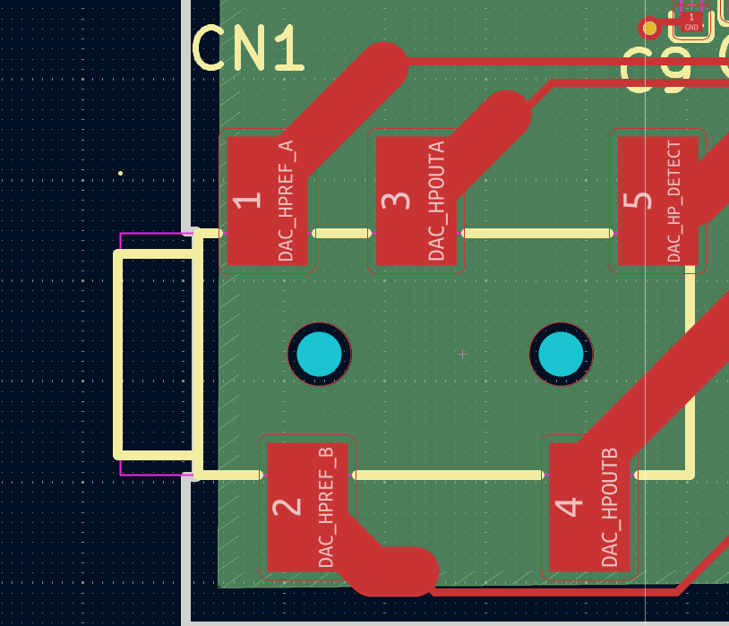
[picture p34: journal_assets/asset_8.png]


This is the only change in the PCB, which required me to move the MCU a bit to the right along with rerouting all the traces connected to the MCU.

What this does is give us enough room for the enclosure to expose the audio jack hole after factoring in tolerance offsets of the 3d print and the male connector's housing (which could've potentially caused badly connected jack if I had not fixed this).

This was all for revision 1.5.

## Main Case

This took up a big chunk of my time.

After redoing the entire thing countless times while Fusion360 kept crashing or freezing, I finally completed the enclosure for the Main Board. This required me to watch a lot of YouTube tutorials and read about 3D Printing limitations, some of which I have linked in the references section of this journal.

### Preview Images:

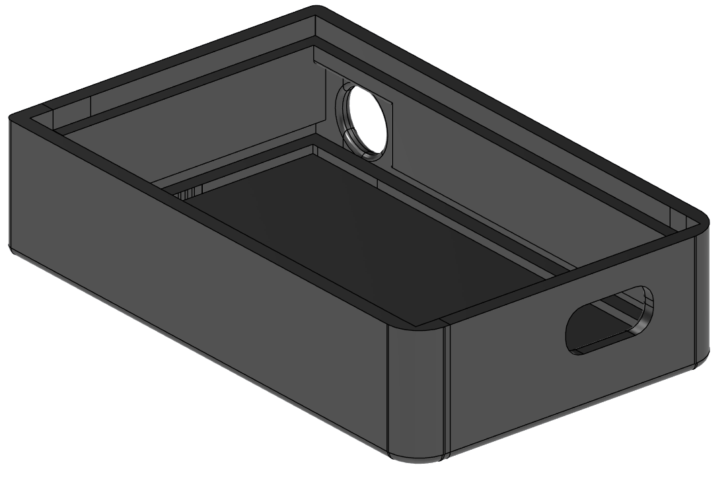
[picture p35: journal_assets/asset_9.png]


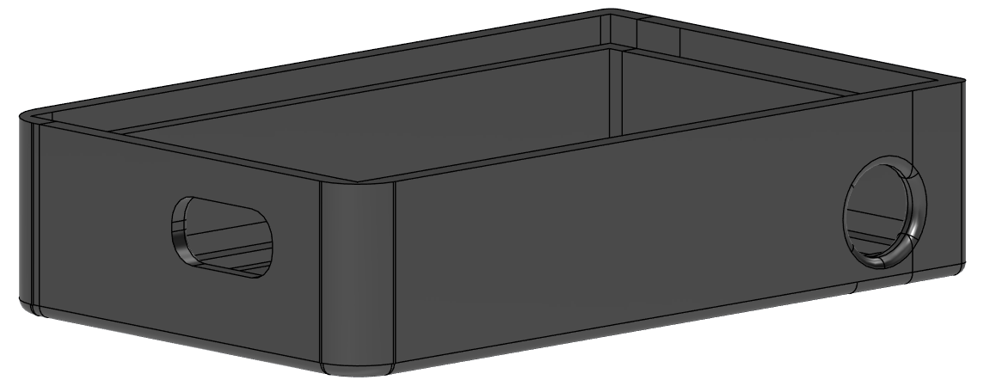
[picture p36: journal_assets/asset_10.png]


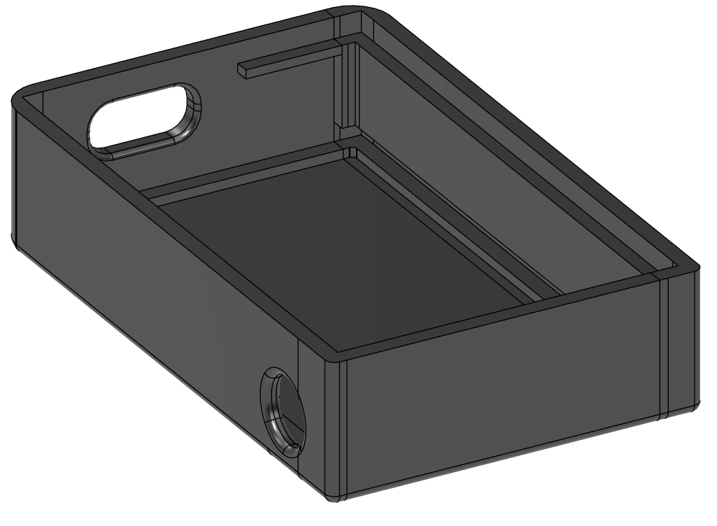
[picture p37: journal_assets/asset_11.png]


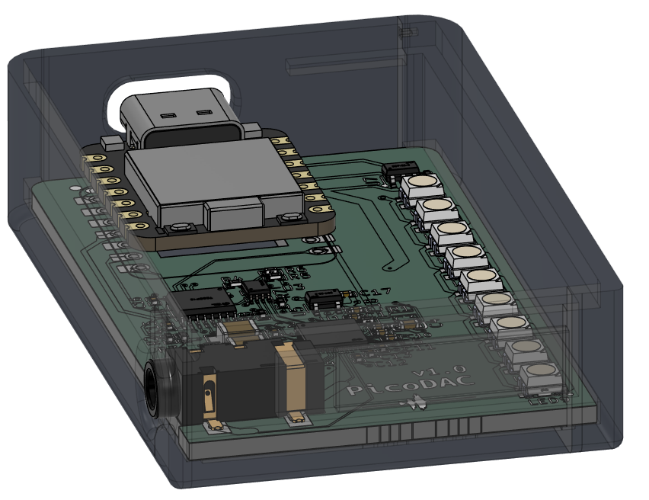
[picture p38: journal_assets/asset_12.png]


I made the enclosure a cuboidal shape with one side that is detached, to slide in the PCB.

The detached side is friction-fit using cuboidal and cylindrical extrusions on both ends.

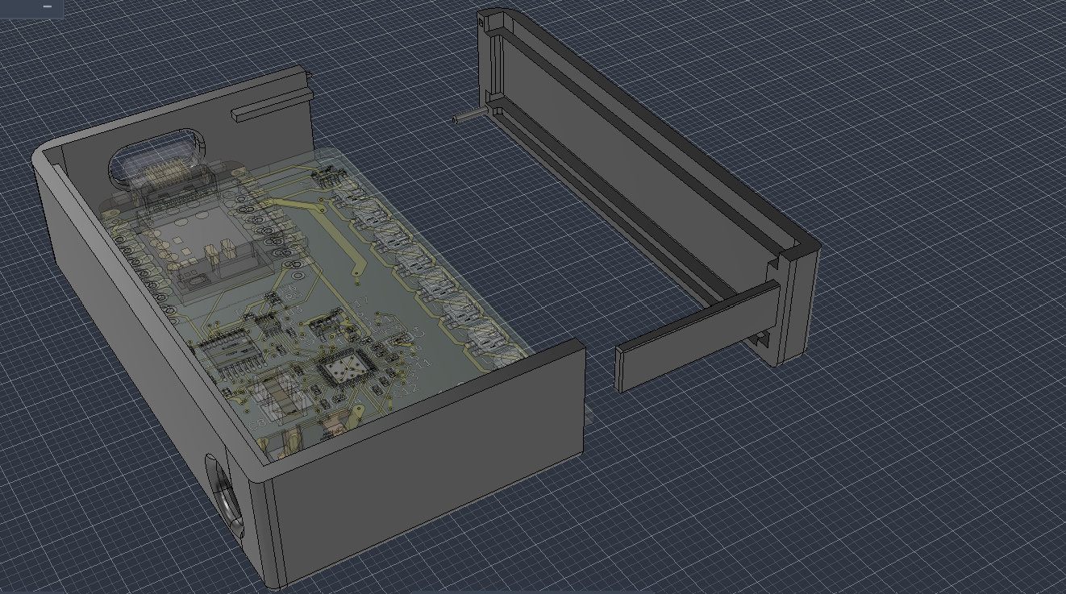
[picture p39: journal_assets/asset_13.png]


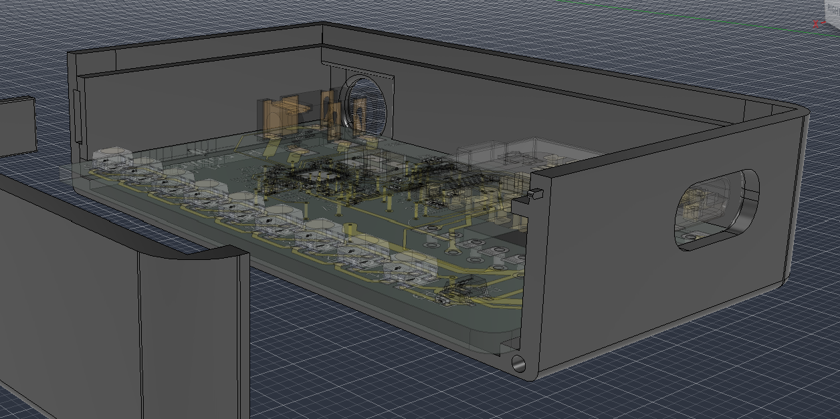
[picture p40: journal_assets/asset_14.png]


The top face of the cuboidal case is empty with a 2.2mm depression and lips, to hold in place a custom cut transparent acrylic sheet of thickness 2mm. (0.2mm is tolerance value). The dimensions for this acrylic cutout would be:


The acrylic sheet will be fixed using superglue / something appropriate to the bigger part of the cuboidal case, but not to the detachable side.

I did it like this so that the PCB is visible from the top of the case (which would look really cool) and also the LED strip would also look really cool when viewed like that. (I'm a fan of see-through electronics!!)

As for Board-2, due to it's small size and relatively simpler shape / dimensions I've decided to make the enclosure for it later. There is also the issue of incorrectly offset clamp/side mount USB-C connector in the exported model from KiCAD so that is also one of the reasons for this delay.

For the time being, I've decided to finish the firmware part and after completing that, I will be finally making the enclosure for Board-2.

## Thank you for reading my journal
*I Hate Fusion360.*

## References
- https://www.youtube.com/watch?v=E0NVC8xhf3I
- https://www.youtube.com/watch?v=TfK47vLOg90
- https://www.youtube.com/watch?v=BmFbxpeXbW0
- https://www.youtube.com/watch?v=GnqhoQHuEq8
- https://www.raise3d.com/blog/3d-printing-wall-thickness/
- https://jlc3dp.com/help/article/3d-printing-design-guideline
- https://wikifactory.com/+wikifactory/stories/ultimate-guide-how-to-design-for-3d-printing
<br>

**Total time spent: 4 hours**

# 2026-08-19: PCB Rev 1.4
## PCB Revision 1.4

This journal describes all the changes that I mentioned I needed to do in the last journal.

## Capacitors

Originally I used small 0201 package capacitors which required `Standard` assembly at JLCPCB, which ramped up costs of the PCB. So I switched to 0402 package capacitors ((C170151)[https://www.lcsc.com/datasheet/C170151.pdf]).

This meant redoing the PCB portions wherever the 0201 capacitors were used, which I did.

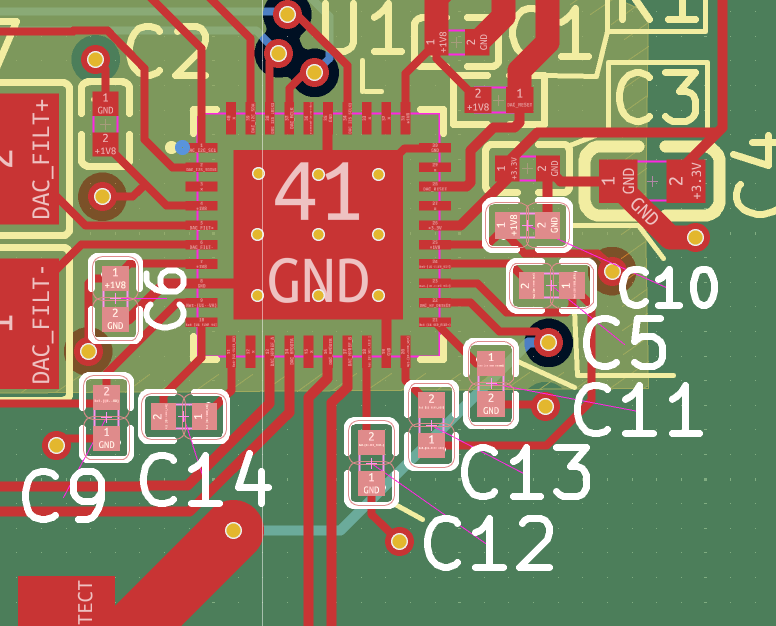
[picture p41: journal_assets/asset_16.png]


## USB-C connector

The side mount clamp USB-C connector was marked as `Standard` assembly only, So I found an alternative replacement for it which had both options for `Economy` and `Standard` assembly and redid the PCB portion of that too.

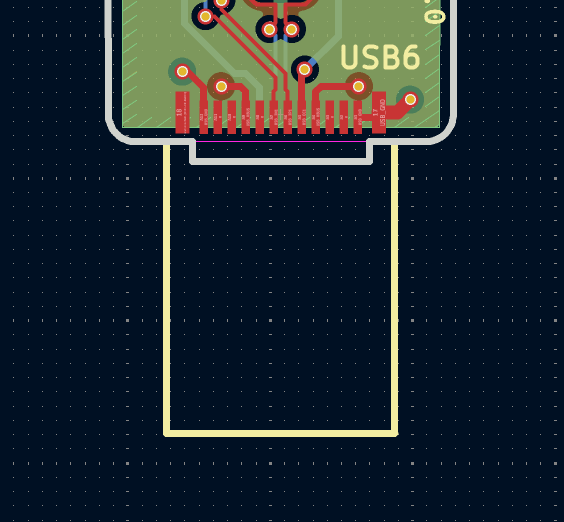
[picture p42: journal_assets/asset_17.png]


## SK6812 LEDs

The previously selected SK6812 LEDs were also marked as `Standard` assembly only, So again I found alternative replacement for it and redid the PCB portion of it. I could not find one that was the same size as the previously selected ones (5.4x5mm) so I settled with using the currently available (3.5x2.8mm) size SK6812 LEDs.

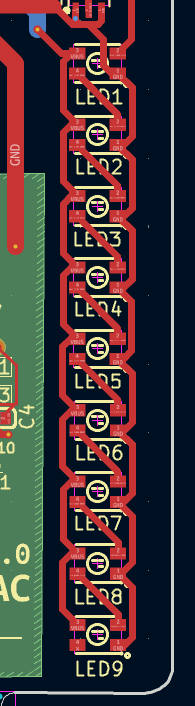
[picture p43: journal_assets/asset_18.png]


## Heat relief vias

Originally, I had done the GND vias below the CS43131 IC by hand, eyeballing the positions and had forgotten about it.

I fixed it by using the position tools in KiCAD (Shift + P) using proper relative positions, with 1.25mm gaps between each vias in the 3x3 via grid.

I also made the via size smaller to 0.4mm and drill 0.2mm after reading about [Solder drainage](https://www.eurocircuits.com/technical-guidelines/pcb-assembly-guidelines/solder-escape-wick/).

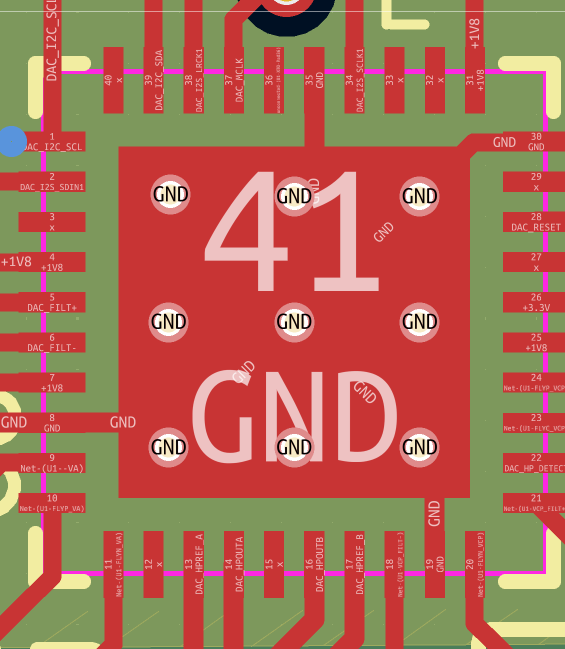
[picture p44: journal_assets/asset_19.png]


## Final Board looks

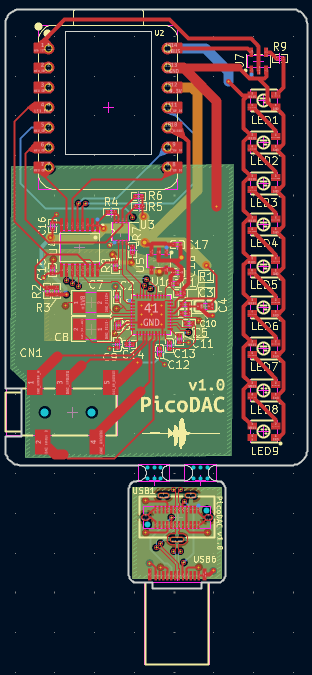
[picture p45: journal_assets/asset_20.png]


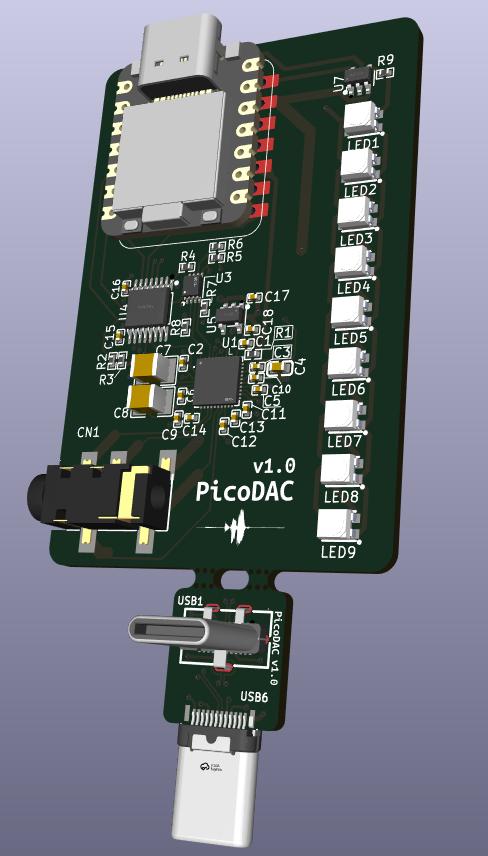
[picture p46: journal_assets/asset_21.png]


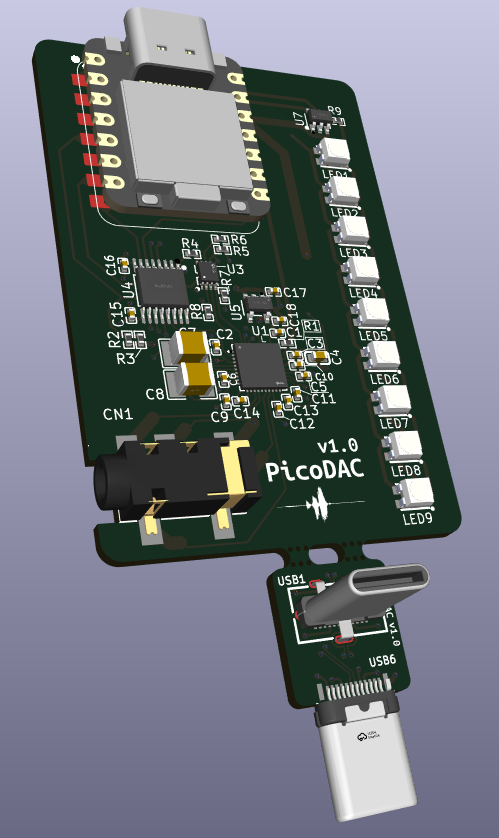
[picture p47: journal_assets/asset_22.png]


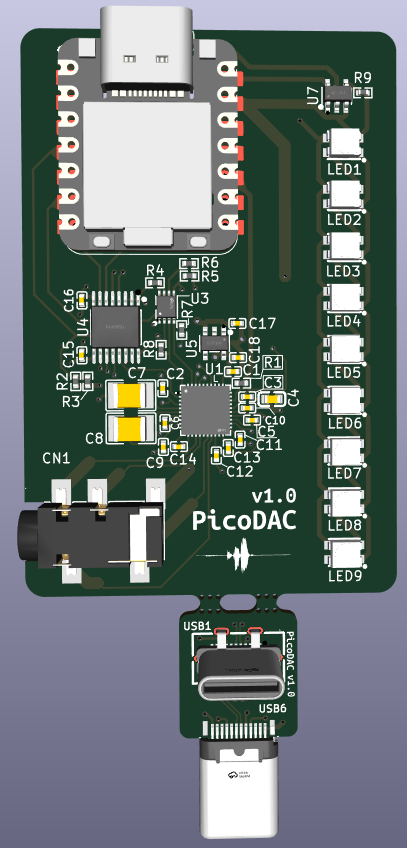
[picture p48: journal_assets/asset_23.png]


## Final Cost

Even after doing all that, the final cost for assembly came out to be `88.55$`. However, I'm sure I can bring it down a bit using coupons and slower shipping etc.

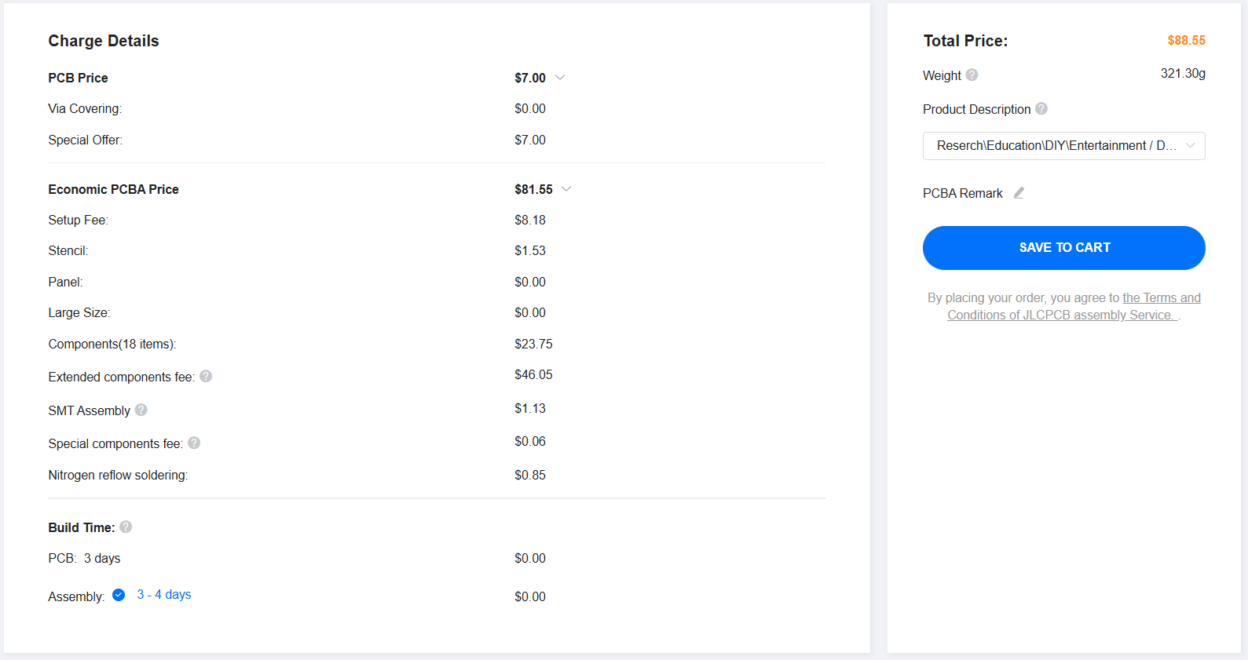
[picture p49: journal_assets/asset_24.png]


## Next steps

Now, I will be moving on to the CAD case for this.

## ***Thank you***
<br>

**Total time spent: 2 hours**

# 2026-08-18: LED Positions update + Mousebites + PCB Rev 1.2
## PCB Rev 1.2

I fixed all fixable DRC errors and rounded the PCB corners so that they do not cut my fingers during assembly.

## LED Positions

I moved LEDs a bit down and repositioned the resistor and the logic level translator such that the LED bar would start from (almost) the bottom of the board with a little bit of padding at the bottom. This was done to make the board look aesthetically better.

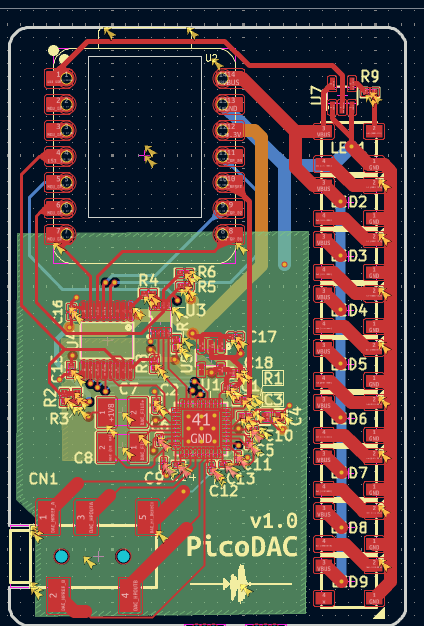
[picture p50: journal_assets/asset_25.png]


## Mousebites

I connected the Main Board with Board - 2 using 2 mousebite tabs.

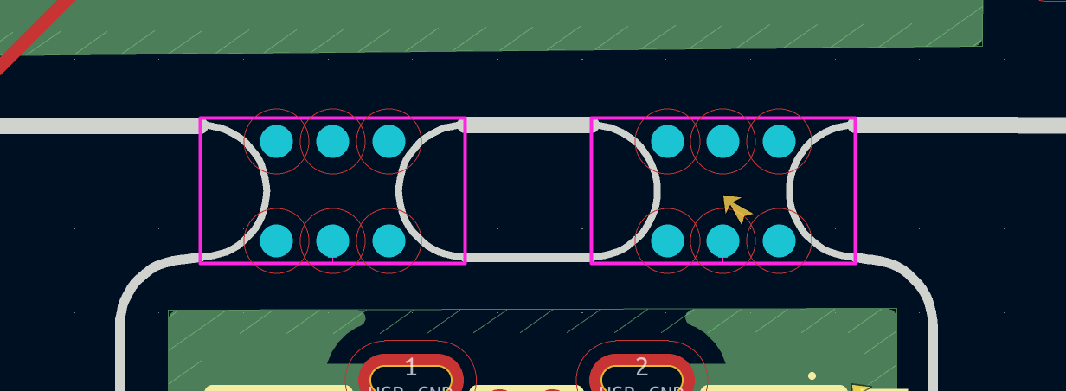
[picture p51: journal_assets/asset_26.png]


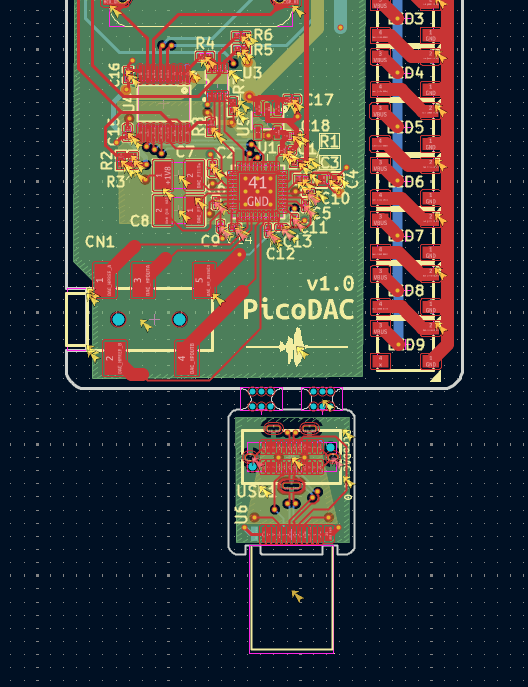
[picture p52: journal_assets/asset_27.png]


## 3D View

After fixing all the DRC errors, the 3d view finally showed how the board would actually look:

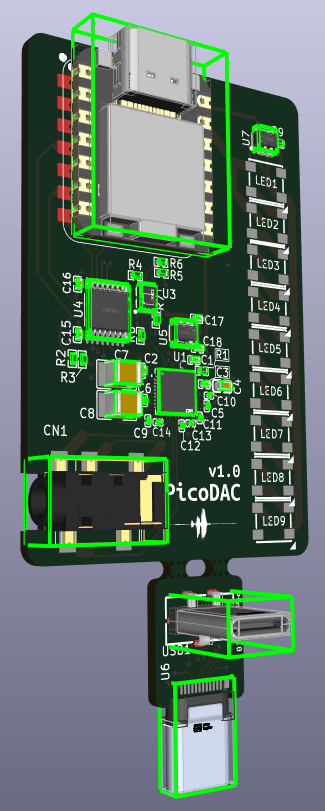
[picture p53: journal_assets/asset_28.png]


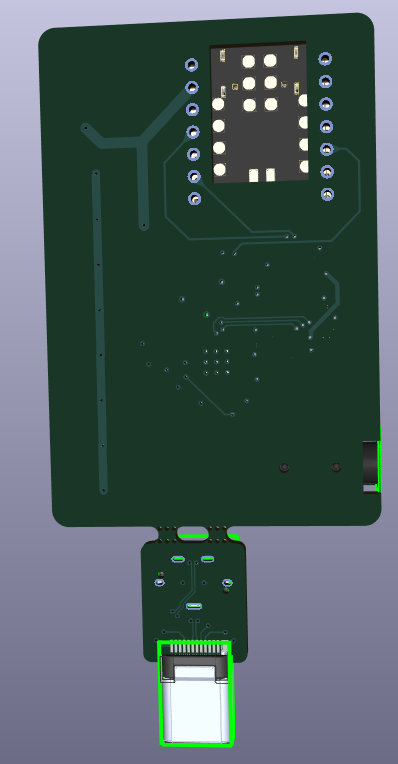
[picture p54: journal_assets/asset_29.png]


## JLC PCB and Assembly costs

I finished exporting the gerber zip file using [Fabrication toolkit](https://github.com/bennymeg/Fabrication-Toolkit). I tried to use it for BOM and CPL files too but JLC did not accept those (they were missing information for some reason) so I used the built-in KiCad BOM and CPL file exporter tool under the Fabtrication outputs menu and manually edited them such that they worked with JLCPCB.

Finally, after uploading everything and selecting appropriate options, The grand total for 5 PCBS (2 assembled) came out to be `$95.49`, excluding shipping:

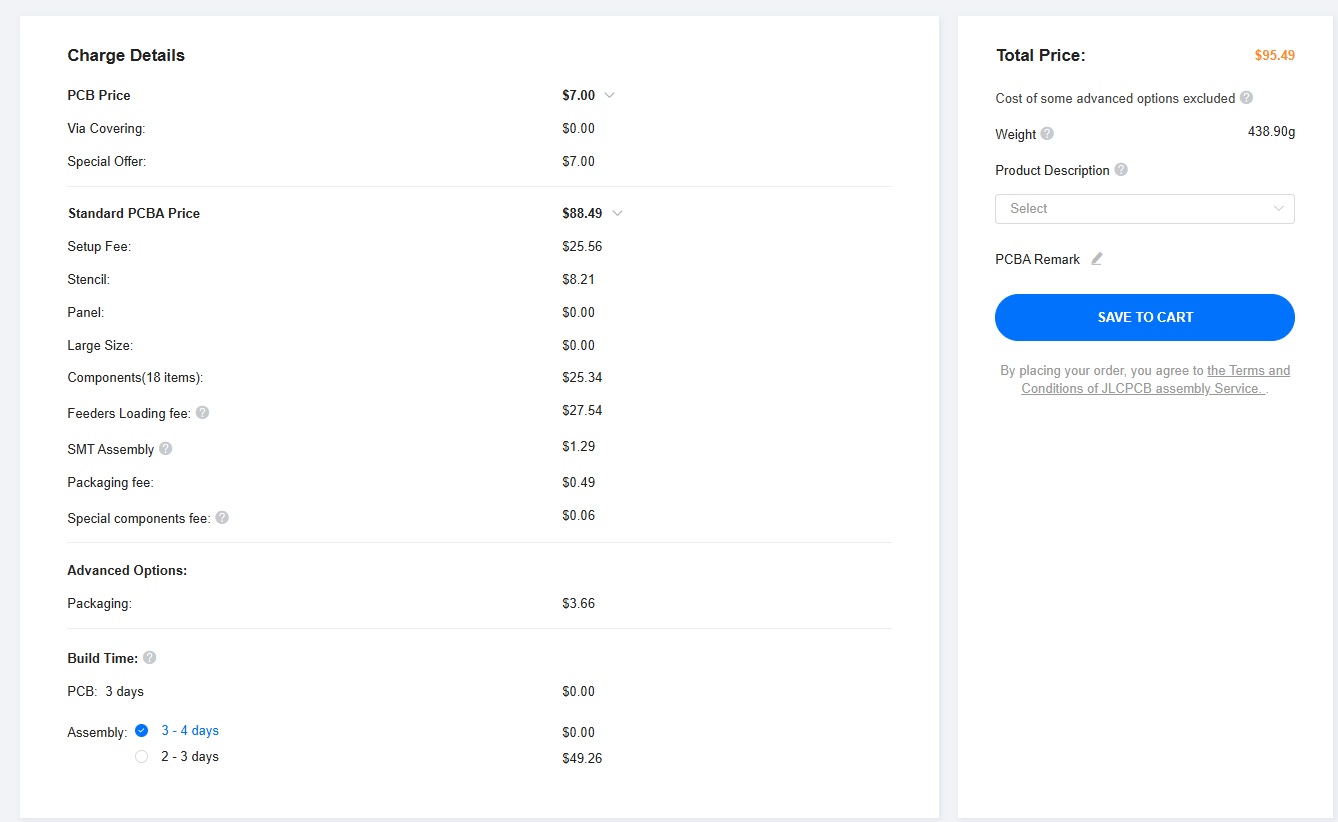
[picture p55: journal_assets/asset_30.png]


However, this was because some components that I selected required `Standard` PCBA instead of `Economy`, which added 25$ additional fees along with other prices. 

Hence, I will be trying to make the PCB `Economic` assembly next, so that the costs can be lowered.

This includes:
- C5,C6,C9,C10,C11,C12,C13,C14 (2.2uF) capacitors, 0201 package
- SK6812 LEDs (LCSC ID: C5378720)
- Clamping type USB-C plug (LCSC ID: C3151751)

I will try to find alternative parts that can be used with economic assembly, finish the PCB and then hopefully move on to the CAD case part of the project after fixing any other problems if encountered.

## Thank you for reading my journal!
<br>

**Total time spent: 2 hours**

# 2026-08-16: LED Placement update + PCB Art + Misc
## LED Placement update

I moved the LED row to the Main Board instead of Board - 2 as it was getting too big for just a USB-C male to male extender connection board and also required an external wire to be soldered to solder pads on Main Board and Board - 2.

This comes with 2 benefits:

1. **Tinyyy Board - 2, No solder pads:**

    Board 2 size is now 12.313 x 14.112 mm (excluding the USB-C male protruding connector) which is incredibly small! Also since the LEDs are on the main board, unlike the previous version, no solder pads are required now.

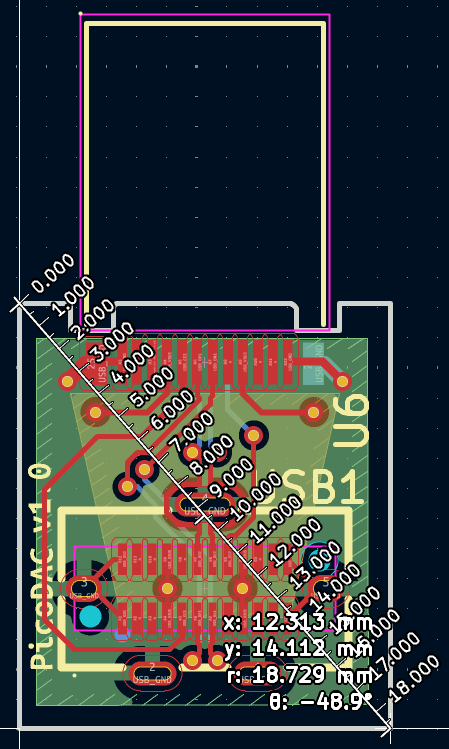
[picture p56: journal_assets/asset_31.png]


2. **9 LEDs instead of only 4:**

    Since adding 4 LEDs to the main board leaves a lot of empty space, I jumped up to 9 since they fit perfectly, leaving minor spaces at the top and bottom.

    I made sure to use thick enough traces for the power and ground rails, connecting the power rail directly to the MCU's VBUS pin (which would be +5V).

    The Main board now looks like this:
    
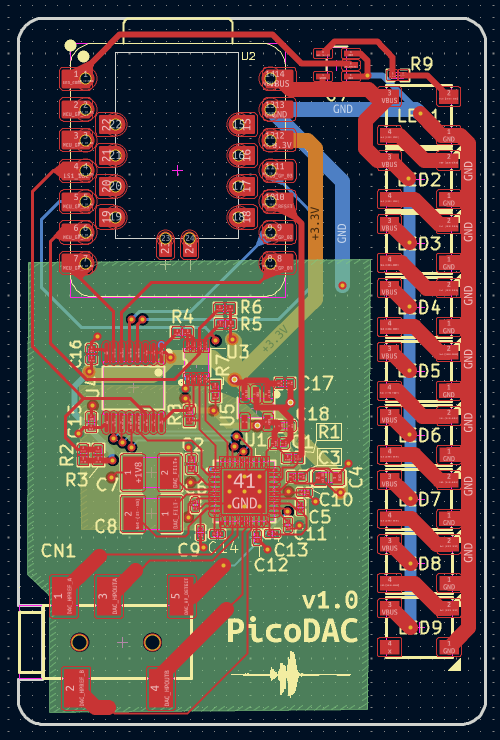
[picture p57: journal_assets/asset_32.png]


    I'm thinking of using a light diffusing sheet to maybe diffuse the LED lights into a color bar, but I have not yet decided on how exactly I'm going to be doing this. So this is a thought for later, when I make the case for the main board.

## Updated schematics

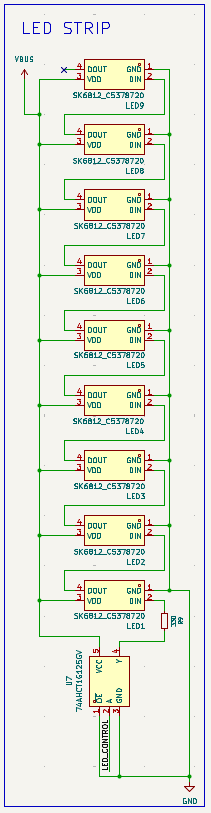
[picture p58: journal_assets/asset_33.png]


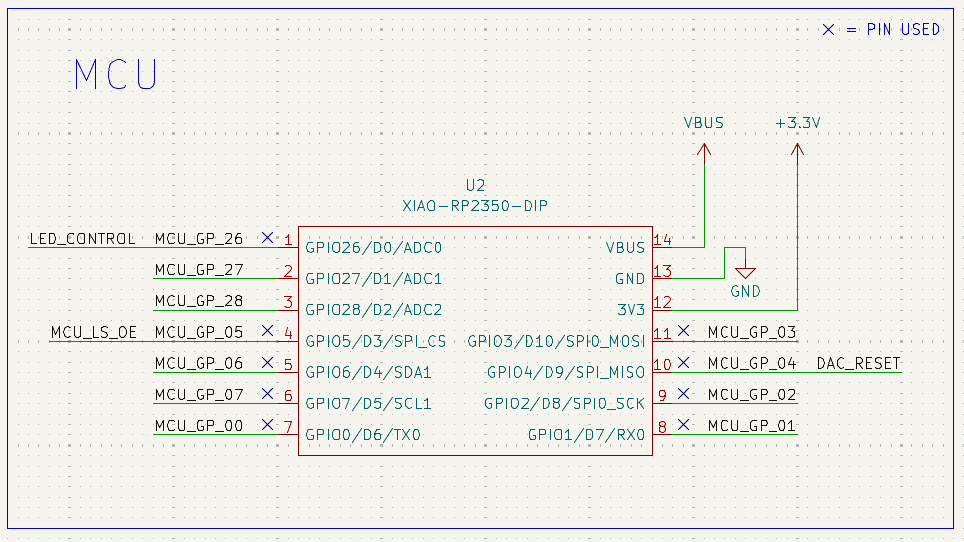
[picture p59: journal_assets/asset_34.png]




## PCB Art

I was wondering on how to "brand" my PCB such that it accurately depicts what this project is.

As you might have noticed in the previous Main Board picture, I decided to go with an audio waveform graph, generated from my own voice, where I recorded myself saying the name of this project, "PicoDAC". It looks amazing on the PCB and I hope it looks the same when I physically get the PCB.

The logo I made from the waveform (this is supposed to be a small pic):



The actual audio waveform looks like this:



And, on the main board, it looks like this:





## Misc

Other than that, I changed the shape and dimensions of the ground plane on the main board and replaced the thick power traces on board - 2 with a dedicated power plane.

## **Rough sketch of the Main-Board and it's case:**



## Next steps

Next I will be 
- fixing DRC errors (there are a lot, related to tolerances etc.)
- adding mousebites in between Board - 2 and the Main Board to easily break it off after I get the PCB.
<br>

**Total time spent: 3 hours**

# 2026-08-14: Main Board
## Main Board PCB

I finally finished the revision 1 of the main PCB after again checking all the datasheets, verifying connections, placing the capacitors as close to the pins as physically possible etc.

The board, just like Board - 2, is a 4 layer PCB (signal, ground, power, signal).

This took quite a lot of time again, as the DAC schematics were a mess. The level shifters were easier but placing all these components also took a few tries to get correct.

This is of course only the first revision, and I will be changing stuff like orientations, component placements etc. over the next revisions.

I also have not added proper silkscreen art yet (Only name and version are on the board currently) that I will be doing later along with the Board-2 silkscreen art.

**This is how the schematics look, excluding the ground and power layer.**



**With the power layer:**



**Finally, with the ground layer:**



I made the edges of the board a bit rounded to make it look good and hopefully not accidentally cut myself as the edges of PCBs can be quite sharp (speaking from prior experience ;))

The power plane is split into two different components:
- Thick 3.3V power traces
- 1.8V power plane

I did this to make the 1.8V power as clean as possible as it is used directly by the CS43131.

The 3.3V power traces are also quite thick and should not contribute to any noise or EMI (hopefully) and also should not heat up anywhere.

I added teardrops to the connecting pads of the 3.5mm connector and this is how they currently look:



I have currently decided to put the lights solder pad (testpoint) at the right side of the mcu footprint but this might change later on, depending upon how I make the case for this:



This is the DAC part of the PCB which I finished after a restarting over and over again a lot of times:



There are some DRC errors that I encountered related to annular width, tolerances, board edges and silkscreen. I ignored all the silkscreen ones (:D) and fixed **some** of the remaining ones, but there are still quite a lot remaining which I will fix in the next journal. Other than that, I will also be fixing any other errors that I can find in both the PCBs and as previously mentioned, updating component placements if required.

Thank you for reading my journal!!! <3

## References
- https://www.lcsc.com/datasheet/C1554754.pdf
- https://www.lcsc.com/datasheet/C668605.pdf
https://www.lcsc.com/product-detail/C2867798.html (english version: https://www.ti.com/lit/ds/symlink/sn74axc4t245.pdf)
- https://www.lcsc.com/datasheet/C51953293.pdf (english version: https://www.alldatasheet.com/datasheet-pdf/pdf/1265214/TI/TPS7A201825PDQNR.html)
- https://www.lcsc.com/datasheet/C33196.pdf
- https://forum.kicad.info/t/how-to-create-teardrops-in-pcb-editor/61920/
- https://electronics.stackexchange.com/questions/686845/pcb-design-question-power-plane-or-fat-traces-for-high-current
- https://www.eevblog.com/forum/eda/should-plane-be-used-to-connect-power-or-just-thicker-tracks/
<br>

**Total time spent: 4 hours**

# 2026-08-12: Board-2
## Board-2 PCB

I completed routing board-2 PCB after restarting from scratch multiple times while checking datasheets, clearance values and youtube tutorials. The USB-C connectors were especially hard for a first time. At the end, I'm pretty satisfied with how it all turned out, even though it took quite a long time.

Since my main board is also a 4-layer PCB with stackup:
- Signal (Top layer, `F.Cu`)
- Ground Layer (`In1.Cu`)
- Power Layer (`In2.Cu`)
- Signal (Bottom layer, `B.Cu`)

I made board 2 with the same layer stackup as the board-2 will be attached to the main board using mousebites or V-Cuts.

## USB-C

I had to manually edit some footprint properties of the vertical USB-C connector to fix some DRC errors and also changed the Side mount USB-C connector to a different one as the previous one's footprint was weird ish.

I also changed schematics of the USB-C connectors to exclude signal traces like `SSTX` and `SSRX` since our MCU will not be using those pins and they were unnecessarily increasing the PCB complexity.



I made sure to route the Dp/D+ and Dn/D- pins as a differential pair to each USB-C connector.

Other than that, I directly connected relevant pins with each other on the USB-C connectors.



(Ground and power are on separate planes so those pins are just connected to vias)

## LEDs

I routed all the LEDS together as a 4x1 row with thick-enough traces. 



## Level Shifter for LED + Solder pad

I routed the 74AHCT1G125GV level shifter to the LEDs, power and the TestPoint solder pad that will be connected to a similar solder pad on the main board via a wire.



That was pretty much it, the finished board looks like this:

Without ground plane and power layer:



With thick power traces layer:



With ground plane:



I've yet to style the board, and will be doing that later after finishing the main board PCB.

Thank you for reading this journal!

## References
- https://www.pcbway.com/blog/PCB_Design_Layout/USB_Type_C_PCB_Design_Guidelines_Layout_and_Routing_Best_Practices_55bc0c39.html
- https://support.microchip.com/s/article/USB-Type-C-Layout-Recommendations
- https://ledpixelstrip.com/sk6812-rgb-led-strip-the-ultimate-guide/
- https://www.reddit.com/r/PCB/comments/1jyc46l/pcb_design_for_sk6812_led_strips/
<br>

**Total time spent: 3 hours**

# 2026-08-05: Final schematics
## Final schematics
This is a long journal so buckle up!

## 1.8V voltage regulator

I chose the XTPS7A2018 voltage regulator to step down 3.3V to 1.8V for supplying to the DAC. 

The reason for going with this specific IC is that it is LDO (Low Dropout Regulator) meaning it can supply stable 1.8V and also as mentioned in the description, "It delivers excellent noise rejection without requiring an additional noise bypass capacitor, while maintaining superior PSRR and line/load transient response.". 

The schematics for it look like:



## GPIO Pin connections

I finished the GPIO connections for all the pins including DAC I2S/I2C, DAC Reset, Level Shifter enable and finally LEDs driver pin (more on LED below).

The schematics for that is:

 

## Board 2

Since I'm using a XIAO RP2350, which comes with a USB-C receptacle (female plug), it can not directly be plugged into a smartphone's USB-C plug (since that is also a female plug).

To solve this issue, I'm making a separate board that will have two USB-C Male plugs both connected to each other like an extender. This board will be designed in such a way that it fits on to the USB-C receptacle on the XIAO-RP2350 and gives us a free USB-C Male plug that we can plug into our Laptop / Smartphone.

It will be included along with the main PCB, separated using mouse-bites so it can be safely broken away and used.

A rough sketch of what I mean:



This does mean that the body of this device will extend a bit backwards of the smartphone's USB-C port, However, I will make sure that the USB-C port does not experience too much stress to ensure it does not break easily like what happened to my old DAC.

## Board - 2 : USB-C M-M Schematics

I used a vertical mount USB-C plug and a side mount USB-C plug.

Since vertical mount USB-C plugs are normally more prone to breaking due to plugging/unplugging stress, It will be used for connecting to the MCU (as there is no need to unplug or remove board-2 from the main board).

The side mount USB-C plug will be used to connect to smartphones / laptops etc.

The schematics for this look like:



## Board - 2 : LED Schematics

I mentioned the idea of having a music level visualizer in the first journal.

For that, I added 4x SK6812 RGB Leds connected to the USB-Vbus and a GPIO pin on the MCU via a single channel level shifter (74AHCT1G125GV). 

The reason for these specific LEDs is partly that they are RGB and also that a row of these LEDs can be controlled by a single GPIO pin. I was short on GPIO pins so I went with it.

The schematics for this looks like:



Since these do consume a fair amount of current at max rating, I will be adding some way to disable the LEDs in software.

Also, since the LEDs exist on Board-2, I added 2mm solder pads using test point footprint to connect a single wire from board 2 to main board. This will connect the GPIO pin that is supposed to control the LEDs with the level shifter pin. The schematics for that look like:




Where TP1 is on Board-2 and TP2 is on main board.

This sums up all the schematics of the PCB. Now I can move on to actually designing the PCB next!

The entire finished schematics are:



## References
Some of the datasheets were in Chinese so I had to translate parts of it to english using google translate...
- https://www.lcsc.com/datasheet/C51953293.pdf
- https://www.lcsc.com/datasheet/C2840398.pdf
- https://www.lcsc.com/datasheet/C2895018.pdf
- https://wiki.seeedstudio.com/xiao_rp2350_arduino/
- https://www.lcsc.com/datasheet/C52140417.pdf
- https://www.lcsc.com/datasheet/C5378720.pdf

Thank you for reading my journal, Until next time!
<br>

**Total time spent: 3 hours**

# 2026-08-04: schematics update
This is a pretty long journal that I've finally written after locking-in for nearly 4 hours.

## DAC Schematics

I finished the CS43131 schematics after carefully referencing the datasheet of the CS43131 by completing the VCP_FILT circuit, adding labels to required pins, cleaning up the previous schematics a bit and now it finally looks like this:



Note the `DAC_RESET` label, It will be connected to some GPIO pin on the MCU to pull the RESET pin of the DAC low, which will enable the DAC as it is active low.

## Logic level shifters

According to the information in the CS43131 datasheet, the logic pins on it run at 1.8V and since the microcontroller I'm using (RP2350A) has GPIO pins at 3.3v logic level, I had to use logic level shifters to shift 3.3V to 1.8V.

I used two different ICs to achieve this:

- TI SN74AXC4T245PWR for level shifting I2S as it is one directional and has 4 channels, exactly the number which I needed for I2S. The schematics for it looks like this:


The `MCU_LS_OE` label will be connected to another GPIO pin that will be pulled low BEFORE pulling `DAC_RESET` low to ensure proper functioning and communication between the MCU and the DAC.

- PCA9306 for level shifting I2C as it is bi-directional and has 2 channels, also exactly the number which I needed for I2C. The schematics for it look like this:


I've left this one to always enabled as it is active high and the datasheet's typical application schematic did the same.

**Note that in both the schematics, I've left out the labels for GPIO pin connections as I have not done them yet. I will be doing that next.**

## MCU schematics

I added labels and connected power and ground to the XIAO RP2350's schematic.



## Next steps

As mentioned previously, I will be connecting the GPIO pin labels to the required DAC pins in the level shifter schematics next.

Also, I will be adding a clean, low noise voltage regulator for 3.3V to 1.8V to supply to the DAC.

Thank you for reading my journal.

## References
- https://www.lcsc.com/datasheet/C1554754.pdf
- https://www.lcsc.com/product-detail/C33196.html
- https://www.lcsc.com/product-detail/C2867798.html (english version: https://www.ti.com/lit/ds/symlink/sn74axc4t245.pdf)
- https://www.totalphase.com/blog/2024/07/what-are-i2c-pull-up-resistors-calculate-their-values/
- https://forum.arduino.cc/t/why-use-a-47k-resistor-between-3-3v-and-sda-and-scl-port-of-esp3266/850553
- https://files.seeedstudio.com/wiki/XIAO-RP2350/res/Seeed-Studio-XIAO-RP2350-v1.0.pdf
<br>

**Total time spent: 3.5 hours**

# 2026-08-04: schematics init
(this journal failed to post last time hence back to back journal above)

## CS43131 Schematics

I started with the schematics for the CS43131.

First, I completed the headphone jack (3.5mm audio jack) connections. I did this with a TRS instead of a TRRS connector as I do not use the mic of my earphones at all.

Headphone jack schematics:



Entire schematics (obviously incomplete) currently look like:



## References:
- https://www.lcsc.com/datasheet/C668605.pdf
- https://www.lcsc.com/datasheet/C1554754.pdf
- https://electronics.stackexchange.com/questions/336836/understanding-audio-jack-connection
- https://electronics.stackexchange.com/questions/95575/how-does-the-phone-detect-if-3-5-mm-jack-circuit-is-closed
<br>

**Total time spent: 1.5 hours**

# 2026-08-03: Init
## **PicoDAC**

This is a HiFi portable USB-C to 3.5mm headphone jack Digital Audio Converter (DAC).

## Motivation

I bought a cheap USB-C to 3.5mm connector recently and it was working perfectly fine until it sadly broke.

The problem? 

I use my phone in bed a lot (yes i know this is a bad habit) vertically with the bottom of my phone resting on my chest. Since the USB-C port is at the bottom of my phone, anything connected to it has to do the heavy lifting of keeping the phone upright.


Naturally, the red part I've highlighted in the image slowly got bent and broke :(

To fix this problem and also make a higher-quality DAC, I've started this project.

## The Idea

A flat plane with a 90deg vertical USB-C male plug, where the flat plane is the PCB containing the DAC circuitry. Side mounted 3.5mm headphone jack and some music level LEDs to make it all look good.

Rough sketch looks like this:

 
(i love paint :3)
- I might change some stuff around depending upon the hardware components and PCB layout but the main idea is what I mentioned above.

I've decided to use:
- 1x CS43131-CNZR (A high-performance, 32-bit resolution, stereo audio DAC that supports up to 384-kHz sampling frequency with integrated low-noise ground-centered headphone amplifiers.): [LCSC part](https://www.lcsc.com/product-detail/C965907.html)
- XIAO RP2350 instead of the 2040 as it has integrated fractional dividers (also see: [this git issue](https://github.com/raspberrypi/pico-sdk/issues/1924))

Next I will be starting with the schematics for the PCB.
<br>

**Total time spent: 1 hours**

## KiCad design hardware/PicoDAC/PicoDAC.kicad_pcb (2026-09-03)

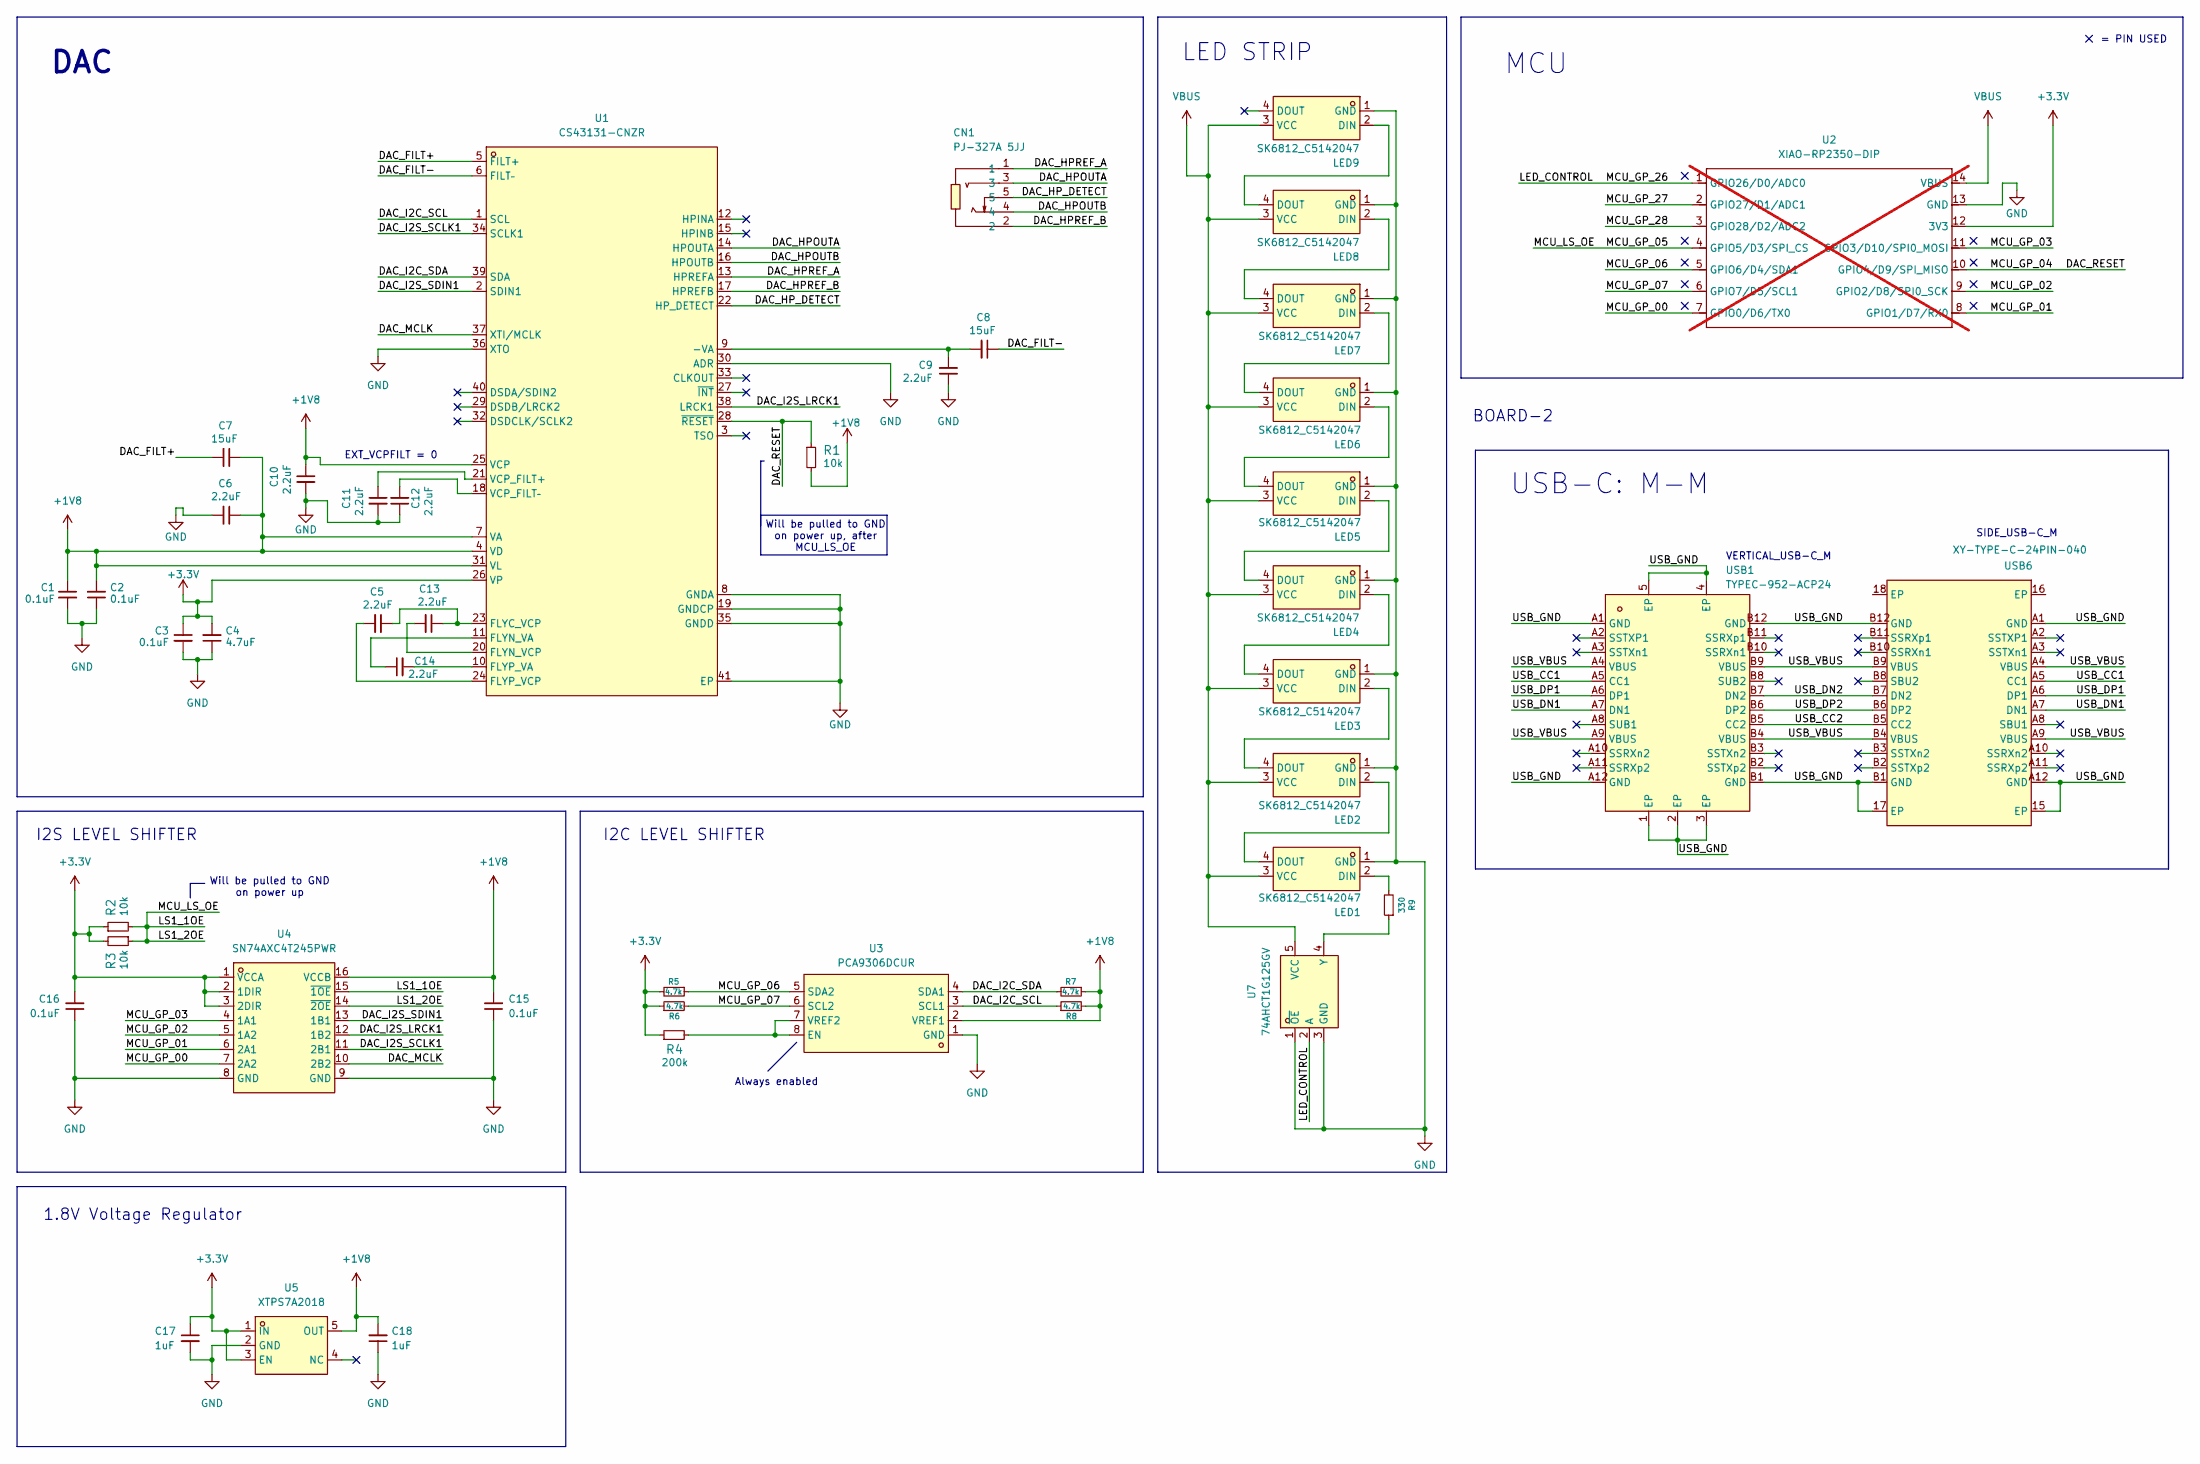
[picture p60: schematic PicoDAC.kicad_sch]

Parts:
C1, C2, C3, C15, C16: 0.1uF; C0402; MPN CL05B104KO5NNNC; LCSC Part C1525
C4: 4.7uF; C0603; MPN CL10A475KO8NNNC; LCSC Part C19666
C5, C6, C9, C10, C11, C12, C13, C14: 2.2uF; C0402; MPN CL05A225KO5NQNC; LCSC Part C170151
C7, C8: 15uF; C1210; MPN C3225X7R1C156MT000N; LCSC Part C694469
C17, C18: 1uF; C0402; MPN CL05A105KA5NQNC; LCSC Part C52923
CN1: PJ-327A 5JJ; AUDIO-SMD_PJ-327A5JJ; MPN PJ-327A 5JJ; LCSC Part C668605
LED1, LED2, LED3, LED4, LED5, LED6, LED7, LED8, LED9: SK6812_C5142047; LED-SMD_4P-L3.5-W2.8-BR-1; MPN SK6812SMINI-ER; LCSC Part C5142047
R1, R2, R3: 10k; R0402; MPN 0402WGF1002TCE; LCSC Part C25744
R4: 200k; R0402; MPN 0402WGF2003TCE; LCSC Part C25764
R5, R6, R7, R8: 4.7k; R0402; MPN 0402WGF4701TCE; LCSC Part C25900
R9: 330; R0402; MPN 0402WGF3300TCE; LCSC Part C25104
U1: CS43131-CNZR; TQFN-40_L5.0-W5.0-P0.40-TL-EP3.5; MPN CS43131-CNZR; LCSC Part C965907
U2: XIAO-RP2350-DIP; not fitted
U3: PCA9306DCUR; SSOP-8_L2.0-W2.3-P0.50-LS3.1-BR; MPN PCA9306DCUR; LCSC Part C33196
U4: SN74AXC4T245PWR; TSSOP-16_L5.0-W4.4-P0.65-LS6.4-BL; MPN SN74AXC4T245PWR; LCSC Part C2867798
U5: XTPS7A2018; SOT-23-5_L3.0-W1.7-P0.95-LS2.8-BL; MPN XTPS7A2018-XC; LCSC Part C51953293
U7: 74AHCT1G125GV; SOT-23-5_L3.0-W1.7-P0.95-LS2.8-BL; MPN 74AHCT1G125GV; LCSC Part C52140417
USB1: TYPEC-952-ACP24; USB-C-SMD_TYPEC-952-ACP24; MPN TYPEC-952-ACP24; LCSC Part C2840398
USB6: XY-TYPE-C-24PIN-040; USB-C-SMD_XY-TYPE-C-24PIN-040; MPN XY-TYPE-C-24PIN-040; LCSC Part C53133501

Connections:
+1V8: C1.1, C2.2, C6.1, C7.1, C10.1, C15.2, C18.2, R1.2, R7.1, R8.2, U1.4 (VD), U1.7 (VA), U1.25 (VCP), U1.31 (VL), U3.2 (VREF1), U4.16 (VCCB), U5.5 (OUT)
+3.3V: C3.1, C4.2, C16.2, C17.1, R2.1, R3.2, R4.1, R5.2, R6.1, U1.26 (VP), U2.12 (3V3), U4.1 (VCCA), U4.2 (1DIR), U4.3 (2DIR), U5.1 (IN), U5.3 (EN)
/DAC_FILT+: C7.2, U1.5 (FILT+)
/DAC_FILT-: C8.1, U1.6 (FILT–)
/DAC_HPOUTA: CN1.3, U1.14 (HPOUTA)
/DAC_HPOUTB: CN1.4, U1.16 (HPOUTB)
/DAC_HPREF_A: CN1.1, U1.13 (HPREFA)
/DAC_HPREF_B: CN1.2, U1.17 (HPREFB)
/DAC_HP_DETECT: CN1.5, U1.22 (HP_DETECT)
/DAC_I2C_SCL: R8.1, U1.1 (SCL), U3.3 (SCL1)
/DAC_I2C_SDA: R7.2, U1.39 (SDA), U3.4 (SDA1)
/DAC_I2S_LRCK1: U1.38 (LRCK1), U4.12 (1B2)
/DAC_I2S_SCLK1: U1.34 (SCLK1), U4.11 (2B1)
/DAC_I2S_SDIN1: U1.2 (SDIN1), U4.13 (1B1)
/DAC_MCLK: U1.37 (XTI/MCLK), U4.10 (2B2)
/DAC_RESET: R1.1, U1.28 (~RESET), U2.10 (GPIO4/D9/SPI_MISO)
/LED_CONTROL: U2.1 (GPIO26/D0/ADC0), U7.2 (A)
/LS1_1OE: R2.2, R3.1, U2.4 (GPIO5/D3/SPI_CS), U4.14 (~2OE), U4.15 (~1OE)
/MCU_GP_00: U2.7 (GPIO0/D6/TX0), U4.7 (2A2)
/MCU_GP_01: U2.8 (GPIO1/D7/RX0), U4.6 (2A1)
/MCU_GP_02: U2.9 (GPIO2/D8/SPI0_SCK), U4.5 (1A2)
/MCU_GP_03: U2.11 (GPIO3/D10/SPI0_MOSI), U4.4 (1A1)
/MCU_GP_06: R5.1, U2.5 (GPIO6/D4/SDA1), U3.5 (SDA2)
/MCU_GP_07: R6.2, U2.6 (GPIO7/D5/SCL1), U3.6 (SCL2)
/MCU_GP_27: U2.2 (GPIO27/D1/ADC1)
/MCU_GP_28: U2.3 (GPIO28/D2/ADC2)
/USB_CC1: USB1.A5 (CC1), USB6.A5 (CC1)
/USB_CC2: USB1.B5 (CC2), USB6.B5 (CC2)
/USB_DN1: USB1.A7 (DN1), USB6.A7 (DN1)
/USB_DN2: USB1.B7 (DN2), USB6.B7 (DN2)
/USB_DP1: USB1.A6 (DP1), USB6.A6 (DP1)
/USB_DP2: USB1.B6 (DP2), USB6.B6 (DP2)
/USB_GND: USB1.1 (EP), USB1.2 (EP), USB1.3 (EP), USB1.4 (EP), USB1.5 (EP), USB1.A1 (GND), USB1.A12 (GND), USB1.B1 (GND), USB1.B12 (GND), USB6.15 (EP), USB6.17 (EP), USB6.A1 (GND), USB6.A12 (GND), USB6.B1 (GND), USB6.B12 (GND)
/USB_VBUS: USB1.A4 (VBUS), USB1.A9 (VBUS), USB1.B4 (VBUS), USB1.B9 (VBUS), USB6.A4 (VBUS), USB6.A9 (VBUS), USB6.B4 (VBUS), USB6.B9 (VBUS)
GND: C1.2, C2.1, C3.2, C4.1, C6.2, C9.1, C10.2, C11.2, C12.1, C15.1, C16.1, C17.2, C18.1, LED1.1 (GND), LED2.1 (GND), LED3.1 (GND), LED4.1 (GND), LED5.1 (GND), LED6.1 (GND), LED7.1 (GND), LED8.1 (GND), LED9.1 (GND), U1.8 (GNDA), U1.19 (GNDCP), U1.30 (ADR), U1.35 (GNDD), U1.36 (XTO), U1.41 (EP), U2.13 (GND), U3.1 (GND), U4.8 (GND), U4.9 (GND), U5.2 (GND), U7.1 (~OE), U7.3 (GND)
unnamed: LED1.2 (DIN), R9.2
unnamed: LED1.4 (DOUT), LED2.2 (DIN)
unnamed: LED2.4 (DOUT), LED3.2 (DIN)
unnamed: LED3.4 (DOUT), LED4.2 (DIN)
unnamed: LED4.4 (DOUT), LED5.2 (DIN)
unnamed: LED5.4 (DOUT), LED6.2 (DIN)
unnamed: LED6.4 (DOUT), LED7.2 (DIN)
unnamed: LED7.4 (DOUT), LED8.2 (DIN)
unnamed: LED8.4 (DOUT), LED9.2 (DIN)
unnamed: C8.2, C9.2, U1.9 (-VA)
unnamed: C5.1, C13.1, U1.23 (FLYC_VCP)
unnamed: C14.1, U1.11 (FLYN_VA)
unnamed: C13.2, U1.20 (FLYN_VCP)
unnamed: C14.2, U1.10 (FLYP_VA)
unnamed: C5.2, U1.24 (FLYP_VCP)
unnamed: C11.1, U1.21 (VCP_FILT+)
unnamed: C12.2, U1.18 (VCP_FILT–)
unnamed: R4.2, U3.7 (VREF2), U3.8 (EN)
unnamed: R9.1, U7.4 (Y)
VBUS: LED1.3 (VCC), LED2.3 (VCC), LED3.3 (VCC), LED4.3 (VCC), LED5.3 (VCC), LED6.3 (VCC), LED7.3 (VCC), LED8.3 (VCC), LED9.3 (VCC), U2.14 (VBUS), U7.5 (VCC)

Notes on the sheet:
Will be pulled to GND on power up
I2S LEVEL SHIFTER
DAC
VERTICAL_USB-C_M
BOARD-2
= PIN USED
MCU
Will be pulled to GND on power up, after MCU_LS_OE
LED STRIP
EXT_VCPFILT = 0
I2C LEVEL SHIFTER
Always enabled
SIDE_USB-C_M
USB-C: M-M
1.8V Voltage Regulator

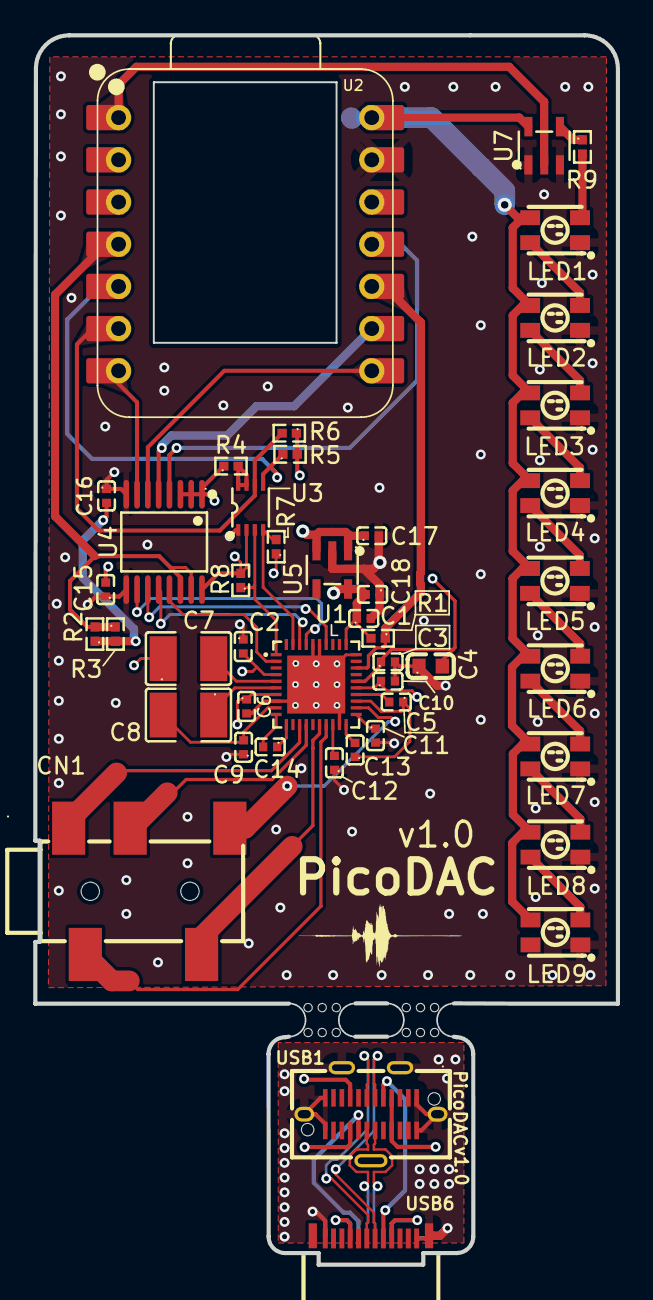
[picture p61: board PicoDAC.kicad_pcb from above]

Board: 4 copper layers, 35.1 x 74.0 mm, 45 parts (0 on the bottom side), 53 nets.

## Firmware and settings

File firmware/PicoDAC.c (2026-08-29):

#include <stdio.h>
#include <string.h>
#include "src/pindefs.h"
#include "pico/stdlib.h"
#include "src/usb_descriptors.h"
#include "tusb.h"
#include "src/common_types.h"

#include "src/neopixel.h"

//--------------------------------------------------------------------+
// HELPER FNS
//--------------------------------------------------------------------+

#define board_millis() to_ms_since_boot(get_absolute_time())

//--------------------------------------------------------------------+
// MACRO CONSTANT TYPEDEF PROTOTYPES
//--------------------------------------------------------------------+

// List of supported sample rates
#if defined(__RX__)
	const uint32_t sample_rates[] = {44100, 48000};
#else
	const uint32_t sample_rates[] = {44100, 48000, 88200, 96000};
#endif

uint32_t current_sample_rate = 44100;

#define N_SAMPLE_RATES TU_ARRAY_SIZE(sample_rates)

/* Blink pattern
 * - 25 ms   : streaming data
 * - 250 ms  : device not mounted
 * - 1000 ms : device mounted
 * - 2500 ms : device is suspended
 */
enum {
  BLINK_STREAMING = 250,
  BLINK_NOT_MOUNTED = 500,
  BLINK_MOUNTED = 1500,
  BLINK_SUSPENDED = 2500,
};

enum {
  VOLUME_CTRL_0_DB = 0,
  VOLUME_CTRL_10_DB = 2560,
  VOLUME_CTRL_20_DB = 5120,
  VOLUME_CTRL_30_DB = 7680,
  VOLUME_CTRL_40_DB = 10240,
  VOLUME_CTRL_50_DB = 12800,
  VOLUME_CTRL_60_DB = 15360,
  VOLUME_CTRL_70_DB = 17920,
  VOLUME_CTRL_80_DB = 20480,
  VOLUME_CTRL_90_DB = 23040,
  VOLUME_CTRL_100_DB = 25600,
  VOLUME_CTRL_SILENCE = 0x8000,
};

static uint32_t blink_interval_ms = BLINK_NOT_MOUNTED;

// Audio controls
// Current states
int8_t mute[CFG_TUD_AUDIO_FUNC_1_N_CHANNELS_RX + 1];  // +1 for master channel 0
int16_t volume[CFG_TUD_AUDIO_FUNC_1_N_CHANNELS_RX + 1];  // +1 for master channel 0

// Buffer for speaker data
uint16_t i2s_dummy_buffer[CFG_TUD_AUDIO_FUNC_1_EP_OUT_SW_BUF_SZ / 2];

void led_blinking_task(void);
void audio_task(void);

#if CFG_AUDIO_DEBUG
	void audio_debug_task(void);
	uint8_t current_alt_settings;
	uint16_t fifo_count;
	uint32_t fifo_count_avg;
#endif

// ------------- MAIN -------------
int main(void) {
	stdio_init_all();

	// led setup
	gpio_init(PIN_ONBOARD_LED);
	gpio_set_dir(PIN_ONBOARD_LED, GPIO_OUT);
  neopixel_init();

	// init device stack on configured roothub port
	tud_init(BOARD_TUD_RHPORT);

	TU_LOG1("device running\r\n");

	while (1) {
		tud_task();  // TinyUSB device task
		led_blinking_task();
		#if CFG_AUDIO_DEBUG
			audio_debug_task();
		#endif
			audio_task();
	}
}

//--------------------------------------------------------------------+
// Device callbacks
//--------------------------------------------------------------------+

// Invoked when device is mounted
void tud_mount_cb(void) { blink_interval_ms = BLINK_MOUNTED; }

// Invoked when device is unmounted
void tud_umount_cb(void) { blink_interval_ms = BLINK_NOT_MOUNTED; }

// Invoked when usb bus is suspended
// remote_wakeup_en : if host allow us  to perform remote wakeup
// Within 7ms, device must draw an average of current less than 2.5 mA from bus
void tud_suspend_cb(bool remote_wakeup_en) {
  (void)remote_wakeup_en;
  blink_interval_ms = BLINK_SUSPENDED;
}

// Invoked when usb bus is resumed
void tud_resume_cb(void) {
  blink_interval_ms = tud_mounted() ? BLINK_MOUNTED : BLINK_NOT_MOUNTED;
}

//--------------------------------------------------------------------+
// Application Callback API Implementations
//--------------------------------------------------------------------+

// Helper for clock get requests
static bool tud_audio_clock_get_request(
    uint8_t rhport, audio_control_request_t const* request) {
  TU_ASSERT(request->bEntityID == UAC2_ENTITY_CLOCK);

  if (request->bControlSelector == AUDIO_CS_CTRL_SAM_FREQ) {
    if (request->bRequest == AUDIO_CS_REQ_CUR) {
      TU_LOG1("Clock get current freq %lu\r\n", current_sample_rate);

      audio_control_cur_4_t curf = {(int32_t)tu_htole32(current_sample_rate)};
      return tud_audio_buffer_and_schedule_control_xfer(
          rhport, (tusb_control_request_t const*)request, &curf, sizeof(curf));
    } else if (request->bRequest == AUDIO_CS_REQ_RANGE) {
      audio_control_range_4_n_t(N_SAMPLE_RATES)
          rangef = {.wNumSubRanges = tu_htole16(N_SAMPLE_RATES)};
      TU_LOG1("Clock get %d freq ranges\r\n", N_SAMPLE_RATES);
      for (uint8_t i = 0; i < N_SAMPLE_RATES; i++) {
        rangef.subrange[i].bMin = (int32_t)sample_rates[i];
        rangef.subrange[i].bMax = (int32_t)sample_rates[i];
        rangef.subrange[i].bRes = 0;
        TU_LOG1("Range %d (%d, %d, %d)\r\n", i, (int)rangef.subrange[i].bMin,
                (int)rangef.subrange[i].bMax, (int)rangef.subrange[i].bRes);
      }

      return tud_audio_buffer_and_schedule_control_xfer(
          rhport, (tusb_control_request_t const*)request, &rangef,
          sizeof(rangef));
    }
  } else if (request->bControlSelector == AUDIO_CS_CTRL_CLK_VALID &&
             request->bRequest == AUDIO_CS_REQ_CUR) {
    audio_control_cur_1_t cur_valid = {.bCur = 1};
    TU_LOG1("Clock get is valid %u\r\n", cur_valid.bCur);
    return tud_audio_buffer_and_schedule_control_xfer(
        rhport, (tusb_control_request_t const*)request, &cur_valid,
        sizeof(cur_valid));
  }
  TU_LOG1(
      "Clock get request not supported, entity = %u, selector = %u, request = "
      "%u\r\n",
      request->bEntityID, request->bControlSelector, request->bRequest);
  return false;
}

// Helper for clock set requests
static bool tud_audio_clock_set_request(uint8_t rhport,
                                        audio_control_request_t const* request,
                                        uint8_t const* buf) {
  (void)rhport;

  TU_ASSERT(request->bEntityID == UAC2_ENTITY_CLOCK);
  TU_VERIFY(request->bRequest == AUDIO_CS_REQ_CUR);

  if (request->bControlSelector == AUDIO_CS_CTRL_SAM_FREQ) {
    TU_VERIFY(request->wLength == sizeof(audio_control_cur_4_t));

    current_sample_rate = (uint32_t)((audio_control_cur_4_t const*)buf)->bCur;

    TU_LOG1("Clock set current freq: %ld\r\n", current_sample_rate);

    return true;
  } else {
    TU_LOG1(
        "Clock set request not supported, entity = %u, selector = %u, request "
        "= %u\r\n",
        request->bEntityID, request->bControlSelector, request->bRequest);
    return false;
  }
}

// Helper for feature unit get requests
static bool tud_audio_feature_unit_get_request(
    uint8_t rhport, audio_control_request_t const* request) {
  TU_ASSERT(request->bEntityID == UAC2_ENTITY_FEATURE_UNIT);

  if (request->bControlSelector == AUDIO_FU_CTRL_MUTE &&
      request->bRequest == AUDIO_CS_REQ_CUR) {
    audio_control_cur_1_t mute1 = {.bCur = mute[request->bChannelNumber]};
    TU_LOG1("Get channel %u mute %d\r\n", request->bChannelNumber, mute1.bCur);
    return tud_audio_buffer_and_schedule_control_xfer(
        rhport, (tusb_control_request_t const*)request, &mute1, sizeof(mute1));
  } else if (request->bControlSelector == AUDIO_FU_CTRL_VOLUME) {
    if (request->bRequest == AUDIO_CS_REQ_RANGE) {
      audio_control_range_2_n_t(1)
          range_vol = {.wNumSubRanges = tu_htole16(1),
                       .subrange[0] = {.bMin = tu_htole16(-VOLUME_CTRL_50_DB),
                                       tu_htole16(VOLUME_CTRL_0_DB),
                                       tu_htole16(256)}};
      TU_LOG1("Get channel %u volume range (%d, %d, %u) dB\r\n",
              request->bChannelNumber, range_vol.subrange[0].bMin / 256,
              range_vol.subrange[0].bMax / 256,
              range_vol.subrange[0].bRes / 256);
      return tud_audio_buffer_and_schedule_control_xfer(
          rhport, (tusb_control_request_t const*)request, &range_vol,
          sizeof(range_vol));
    } else if (request->bRequest == AUDIO_CS_REQ_CUR) {
      audio_control_cur_2_t cur_vol = {
          .bCur = tu_htole16(volume[request->bChannelNumber])};
      TU_LOG1("Get channel %u volume %d dB\r\n", request->bChannelNumber,
              cur_vol.bCur / 256);
      return tud_audio_buffer_and_schedule_control_xfer(
          rhport, (tusb_control_request_t const*)request, &cur_vol,
          sizeof(cur_vol));
    }
  }
  TU_LOG1(
      "Feature unit get request not supported, entity = %u, selector = %u, "
      "request = %u\r\n",
      request->bEntityID, request->bControlSelector, request->bRequest);

  return false;
}

// Helper for feature unit set requests
static bool tud_audio_feature_unit_set_request(
    uint8_t rhport, audio_control_request_t const* request,
    uint8_t const* buf) {
  (void)rhport;

  TU_ASSERT(request->bEntityID == UAC2_ENTITY_FEATURE_UNIT);
  TU_VERIFY(request->bRequest == AUDIO_CS_REQ_CUR);

  if (request->bControlSelector == AUDIO_FU_CTRL_MUTE) {
    TU_VERIFY(request->wLength == sizeof(audio_control_cur_1_t));

    mute[request->bChannelNumber] = ((audio_control_cur_1_t const*)buf)->bCur;

    TU_LOG1("Set channel %d Mute: %d\r\n", request->bChannelNumber,
            mute[request->bChannelNumber]);

    return true;
  } else if (request->bControlSelector == AUDIO_FU_CTRL_VOLUME) {
    TU_VERIFY(request->wLength == sizeof(audio_control_cur_2_t));

    volume[request->bChannelNumber] = ((audio_control_cur_2_t const*)buf)->bCur;

    TU_LOG1("Set channel %d volume: %d dB\r\n", request->bChannelNumber,
            volume[request->bChannelNumber] / 256);

    return true;
  } else {
    TU_LOG1(
        "Feature unit set request not supported, entity = %u, selector = %u, "
        "request = %u\r\n",
        request->bEntityID, request->bControlSelector, request->bRequest);
    return false;
  }
}

// Invoked when audio class specific get request received for an entity
bool tud_audio_get_req_entity_cb(uint8_t rhport,
                                 tusb_control_request_t const* p_request) {
  audio_control_request_t const* request =
      (audio_control_request_t const*)p_request;

  if (request->bEntityID == UAC2_ENTITY_CLOCK)
    return tud_audio_clock_get_request(rhport, request);
  if (request->bEntityID == UAC2_ENTITY_FEATURE_UNIT)
    return tud_audio_feature_unit_get_request(rhport, request);
  else {
    TU_LOG1(
        "Get request not handled, entity = %d, selector = %d, request = %d\r\n",
        request->bEntityID, request->bControlSelector, request->bRequest);
  }
  return false;
}

// Invoked when audio class specific set request received for an entity
bool tud_audio_set_req_entity_cb(uint8_t rhport,
                                 tusb_control_request_t const* p_request,
                                 uint8_t* buf) {
  audio_control_request_t const* request =
      (audio_control_request_t const*)p_request;

  if (request->bEntityID == UAC2_ENTITY_FEATURE_UNIT)
    return tud_audio_feature_unit_set_request(rhport, request, buf);
  if (request->bEntityID == UAC2_ENTITY_CLOCK)
    return tud_audio_clock_set_request(rhport, request, buf);
  TU_LOG1(
      "Set request not handled, entity = %d, selector = %d, request = %d\r\n",
      request->bEntityID, request->bControlSelector, request->bRequest);

  return false;
}

bool tud_audio_set_itf_close_EP_cb(uint8_t rhport,
                                   tusb_control_request_t const* p_request) {
  (void)rhport;

  uint8_t const itf = tu_u16_low(tu_le16toh(p_request->wIndex));
  uint8_t const alt = tu_u16_low(tu_le16toh(p_request->wValue));

  if (ITF_NUM_AUDIO_STREAMING == itf && alt == 0)
    blink_interval_ms = BLINK_MOUNTED;

  return true;
}

bool tud_audio_set_itf_cb(uint8_t rhport,
                          tusb_control_request_t const* p_request) {
  (void)rhport;
  uint8_t const itf = tu_u16_low(tu_le16toh(p_request->wIndex));
  uint8_t const alt = tu_u16_low(tu_le16toh(p_request->wValue));

  TU_LOG2("Set interface %d alt %d\r\n", itf, alt);
  if (ITF_NUM_AUDIO_STREAMING == itf && alt != 0)
    blink_interval_ms = BLINK_STREAMING;

#if CFG_AUDIO_DEBUG
  current_alt_settings = alt;
#endif

  return true;
}

void tud_audio_feedback_params_cb(uint8_t func_id, uint8_t alt_itf,
                                  audio_feedback_params_t* feedback_param) {
  (void)func_id;
  (void)alt_itf;
  // Set feedback method to fifo counting
  feedback_param->method = AUDIO_FEEDBACK_METHOD_FIFO_COUNT;
  feedback_param->sample_freq = current_sample_rate;
}

#if CFG_AUDIO_DEBUG
bool tud_audio_rx_done_post_read_cb(uint8_t rhport, uint16_t n_bytes_received,
                                    uint8_t func_id, uint8_t ep_out,
                                    uint8_t cur_alt_setting) {
  (void)rhport;
  (void)n_bytes_received;
  (void)func_id;
  (void)ep_out;
  (void)cur_alt_setting;

  fifo_count = tud_audio_available();
  // Same averaging method used in UAC2 class
  fifo_count_avg = (uint32_t)(((uint64_t)fifo_count_avg * 63 +
                               ((uint32_t)fifo_count << 16)) >>
                              6);

  return true;
}
#endif

//--------------------------------------------------------------------+
// AUDIO Task
//--------------------------------------------------------------------+

void audio_task(void) {
  // Replace audio_task() with your I2S transmit callback.
  // Here we simulate a callback called every 1ms.
  static uint32_t start_ms = 0;
  uint32_t curr_ms = board_millis();
  if (start_ms == curr_ms) return;  // not enough time
  start_ms = curr_ms;

  uint16_t length = current_sample_rate / 1000 *
                    CFG_TUD_AUDIO_FUNC_1_N_BYTES_PER_SAMPLE_RX *
                    CFG_TUD_AUDIO_FUNC_1_N_CHANNELS_RX;

  if (current_sample_rate == 44100 && (curr_ms % 10 == 0)) {
    // Take one more sample every 10 cycles, to have a average reading speed
    // of 44.1 This correction is not needed in real world cases
    length += CFG_TUD_AUDIO_FUNC_1_N_BYTES_PER_SAMPLE_RX *
              CFG_TUD_AUDIO_FUNC_1_N_CHANNELS_RX;
  } else if (current_sample_rate == 88200 && (curr_ms % 5 == 0)) {
    // Take one more sample every 5 cycles, to have a average reading speed
    // of 88.2 This correction is not needed in real world cases
    length += CFG_TUD_AUDIO_FUNC_1_N_BYTES_PER_SAMPLE_RX *
              CFG_TUD_AUDIO_FUNC_1_N_CHANNELS_RX;
  }

  tud_audio_read(i2s_dummy_buffer, length);
}

//--------------------------------------------------------------------+
// BLINKING TASK
//--------------------------------------------------------------------+
void led_blinking_task(void) {
  static uint32_t start_ms = 0;
  static bool led_state = false;

  // Blink every interval ms
  if (board_millis() - start_ms < blink_interval_ms) return;
  start_ms += blink_interval_ms;

  gpio_put(PIN_ONBOARD_LED, led_state);
  led_state = 1 - led_state;
}

#if CFG_AUDIO_DEBUG
//--------------------------------------------------------------------+
// HID interface for audio debug
//--------------------------------------------------------------------+
// Every 20ms, we will sent 1 debug information report
void audio_debug_task(void) {
	static uint32_t start_ms = 0;
	uint32_t curr_ms = board_millis();
	if (curr_ms - start_ms < 20) return;
	start_ms = curr_ms;
  audio_debug_info_t debug_info;
  debug_info.sample_rate = current_sample_rate;
  debug_info.alt_settings = current_alt_settings;
  debug_info.fifo_size = CFG_TUD_AUDIO_FUNC_1_EP_OUT_SW_BUF_SZ;
  debug_info.fifo_count = fifo_count;
  debug_info.fifo_count_avg = fifo_count_avg >> 16;
  for (int i = 0; i < CFG_TUD_AUDIO_FUNC_1_N_CHANNELS_RX + 1; i++) {
    debug_info.mute[i] = mute[i];
    debug_info.volume[i] = volume[i];
  }

  if (tud_hid_ready()) tud_hid_report(0, &debug_info, sizeof(debug_info));
}

// Invoked when received GET_REPORT control request
// Unused here
uint16_t tud_hid_get_report_cb(uint8_t itf, uint8_t report_id,
                               hid_report_type_t report_type, uint8_t* buffer,
                               uint16_t reqlen) {
  // TODO not Implemented
  (void)itf;
  (void)report_id;
  (void)report_type;
  (void)buffer;
  (void)reqlen;

  return 0;
}

// Invoked when received SET_REPORT control request or
// Unused here
void tud_hid_set_report_cb(uint8_t itf, uint8_t report_id,
                           hid_report_type_t report_type, uint8_t const* buffer,
                           uint16_t bufsize) {
  // This example doesn't use multiple report and report ID
  (void)itf;
  (void)report_id;
  (void)report_type;
  (void)buffer;
  (void)bufsize;
}

#endif

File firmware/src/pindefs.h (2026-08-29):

// dac pins
#define PIN_DAC_MCLK                0
#define PIN_DAC_SCLK1               1
#define PIN_DAC_LRCK1               2
#define PIN_DAC_SDIN1               3
#define PIN_DAC_RESET               4
#define PIN_DAC_SDA                 6
#define PIN_DAC_SCL                 7

// level shifter output enable
#define PIN_MCU_LS_OE               5

// led pins
#define PIN_ONBOARD_NEOPIXEL        22
#define PIN_ONBOARD_NEOPIXEL_PWR    23
#define PIN_ONBOARD_LED             25

#define PIN_LED_CONTROL             26

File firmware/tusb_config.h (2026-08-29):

/*
 * The MIT License (MIT)
 *
 * Copyright (c) 2020 Ha Thach (tinyusb.org)
 * Copyright (c) 2020 Jerzy Kasenberg
 *
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
 */

#ifndef _TUSB_CONFIG_H_
#define _TUSB_CONFIG_H_

#ifdef __cplusplus
extern "C" {
#endif

#include "./src/usb_descriptors.h"

//--------------------------------------------------------------------+
// Board Specific Configuration
//--------------------------------------------------------------------+

// RHPort number used for device can be defined by board.mk, default to port 0
#ifndef BOARD_TUD_RHPORT
#define BOARD_TUD_RHPORT      0
#endif

// RHPort max operational speed can defined by board.mk
#ifndef BOARD_TUD_MAX_SPEED
#define BOARD_TUD_MAX_SPEED   OPT_MODE_DEFAULT_SPEED
#endif

//--------------------------------------------------------------------
// Common Configuration
//--------------------------------------------------------------------

// defined by compiler flags for flexibility
#ifndef CFG_TUSB_MCU
#error CFG_TUSB_MCU must be defined
#endif

#ifndef CFG_TUSB_OS
#define CFG_TUSB_OS           OPT_OS_NONE
#endif

// It's recommended to disable debug unless for control requests debugging,
// as the extra time needed will impact data stream !
#ifndef CFG_TUSB_DEBUG
#define CFG_TUSB_DEBUG        0
#endif

// Enable Device stack
#define CFG_TUD_ENABLED       1

// Default is max speed that hardware controller could support with on-chip PHY
#define CFG_TUD_MAX_SPEED     BOARD_TUD_MAX_SPEED

/* USB DMA on some MCUs can only access a specific SRAM region with restriction on alignment.
 * Tinyusb use follows macros to declare transferring memory so that they can be put
 * into those specific section.
 * e.g
 * - CFG_TUSB_MEM SECTION : __attribute__ (( section(".usb_ram") ))
 * - CFG_TUSB_MEM_ALIGN   : __attribute__ ((aligned(4)))
 */
#ifndef CFG_TUSB_MEM_SECTION
#define CFG_TUSB_MEM_SECTION
#endif

#ifndef CFG_TUSB_MEM_ALIGN
#define CFG_TUSB_MEM_ALIGN        __attribute__ ((aligned(4)))
#endif

/* (Needed for Full-Speed only)
 * Enable host OS guessing to workaround UAC2 compatibility issues between Windows and OS X
 * The default configuration only support Windows and Linux, enable this option for OS X
 * support. Otherwise if you don't need Windows support you can make OS X's configuration as
 * default.
 */
#define CFG_QUIRK_OS_GUESSING   0

//--------------------------------------------------------------------
// DEVICE CONFIGURATION
//--------------------------------------------------------------------

// Expose audio class debug information via HID interface
#ifndef CFG_AUDIO_DEBUG
#define CFG_AUDIO_DEBUG           1
#endif

#ifndef CFG_TUD_ENDPOINT0_SIZE
#define CFG_TUD_ENDPOINT0_SIZE    64
#endif

#define CFG_TUD_HID_EP_BUFSIZE    64

//------------- CLASS -------------//
#define CFG_TUD_AUDIO             1

#if CFG_AUDIO_DEBUG
#define CFG_TUD_HID               1
#else
#define CFG_TUD_HID               0
#endif

#define CFG_TUD_CDC               0
#define CFG_TUD_MSC               0
#define CFG_TUD_MIDI              0
#define CFG_TUD_VENDOR            0

//--------------------------------------------------------------------
// AUDIO CLASS DRIVER CONFIGURATION
//--------------------------------------------------------------------

#define CFG_TUD_AUDIO_FUNC_1_DESC_LEN                                TUD_AUDIO_SPEAKER_STEREO_FB_DESC_LEN

// Enable if Full-Speed on OSX, also set feedback EP size to 3
#define CFG_TUD_AUDIO_ENABLE_FEEDBACK_FORMAT_CORRECTION              0

// Audio format type I specifications
#if defined(__RX__)
#define CFG_TUD_AUDIO_FUNC_1_MAX_SAMPLE_RATE                         48000
#else
#define CFG_TUD_AUDIO_FUNC_1_MAX_SAMPLE_RATE                         96000
#endif

#define CFG_TUD_AUDIO_FUNC_1_N_CHANNELS_RX                           2

// 16bit in 16bit slots
#define CFG_TUD_AUDIO_FUNC_1_N_BYTES_PER_SAMPLE_RX                   2
#define CFG_TUD_AUDIO_FUNC_1_RESOLUTION_RX                           16

// EP and buffer size - for isochronous EP´s, the buffer and EP size are equal (different sizes would not make sense)
#define CFG_TUD_AUDIO_ENABLE_EP_OUT                                  1

#define CFG_TUD_AUDIO_FUNC_1_EP_OUT_SZ_MAX        TUD_AUDIO_EP_SIZE(CFG_TUD_AUDIO_FUNC_1_MAX_SAMPLE_RATE, CFG_TUD_AUDIO_FUNC_1_N_BYTES_PER_SAMPLE_RX, CFG_TUD_AUDIO_FUNC_1_N_CHANNELS_RX)
#define CFG_TUD_AUDIO_FUNC_1_EP_OUT_SW_BUF_SZ     (TUD_OPT_HIGH_SPEED ? 32 : 4) * CFG_TUD_AUDIO_FUNC_1_EP_OUT_SZ_MAX // Example read FIFO every 1ms, so it should be 8 times larger for HS device

// Enable feedback EP
#define CFG_TUD_AUDIO_ENABLE_FEEDBACK_EP                             1
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

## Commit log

2026-08-04 added level shifters, finished DAC schematics
    [PicoDAC.kicad_sch]
2026-08-05 finished schematics (led, usb_c_m-m board + 1.8v voltage regulator)
    [PicoDAC.kicad_sch]
2026-08-05 add new revision design, final schematics image
2026-08-07 updated footprints for resistors, capacitors
    [PicoDAC.kicad_sch]
2026-08-07 generated bom
    [bom.csv]
2026-08-14 main board rev1
    [PicoDAC.kicad_pcb, PicoDAC.kicad_sch]
2026-08-14 added bom hyperlink, readme motivation update
2026-08-16 update LEDs position, misc changes to PCBs
    [PicoDAC.kicad_pcb, PicoDAC.kicad_sch]
2026-08-16 updated README on previous pcb changes, added new rough sketch
    [bom.csv]
2026-08-17 moved the LEDs a bit down, repositioned LEDs logic level translator and resistor
    [PicoDAC.kicad_pcb, PicoDAC.kicad_sch]
2026-08-17 updated main board preview image
2026-08-18 final pcb, rev 1.2
    [PicoDAC.kicad_pcb]
2026-08-18 add export files that worked at jlc
    [bom.csv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]
2026-08-18 changed components to get economic assembly
    [PicoDAC.kicad_pcb, PicoDAC.kicad_sch, bom.csv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]
2026-08-19 pcb rev 1.4
    [PicoDAC.kicad_pcb]
2026-08-19 pcb rev 1.4, final touches
    [PicoDAC.kicad_pcb, bom.csv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]
2026-08-19 remove working_exports dir to keep it local only
    [bom.csv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]
2026-08-20 rev 1.5
    [PicoDAC.kicad_pcb]
2026-08-21 main 3d case, design section update
    [Main_Case.step, PicoDAC_Case_Main.f3z]
2026-08-21 setup example from github.com/sekigon-gonnoc/Pico-PIO-USB/tree/main/examples/host_hid_to_device_cdc
2026-08-24 fixed floating xto pin
    [PicoDAC.kicad_pcb, PicoDAC.kicad_sch]
2026-08-28 renamed pcb models, added printing models
    [1_PicoDAC_Case_DetachablePart.step, 2_PicoDAC_Case_Main.step, Main_Case_DoNotPrint.step]
2026-08-29 get led working, change board to pico 2
    [PicoDAC.kicad_pcb]
2026-08-29 added pin reference
2026-08-29 updated pin references in readme w neopixel pins
2026-08-29 updated readme with current firmware status
2026-08-29 removed pin prefix as this is readme and does not require it
2026-08-29 finished current state firmware readme
2026-08-29 optimized parts (this reduced cost a lot)
    [PicoDAC.kicad_sch]
2026-08-29 added ordering instructions, files
    [bom.csv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]
2026-08-29 added cad 3d printing info
2026-08-29 finished board-2 case
    [3_board2_top_case.step, 4_board2_bottom_case.step, PicoDAC_board2_PCB.step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]
2026-08-29 added acrylic lid cad, updated bom
    [Main_Case_Lid_DoNotPrint.dxf]
2026-08-29 added stl format files
    [1_PicoDAC_Case_DetachablePart.stl, 2_PicoDAC_Case_Main.stl, 3_board2_top_case.stl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]
2026-08-30 fixed bom links
2026-09-03 added ground fill on top and bottom layer
    [PicoDAC.kicad_pcb]
2026-09-03 updated bom according to new gerber
2026-09-03 fixed bom
2026-09-04 removed slot friction fit with screw hole
    [1_PicoDAC_Case_DetachablePart.step, 1_PicoDAC_Case_DetachablePart.stl, 2_PicoDAC_Case_Main.step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]
2026-09-04 added screw mount
2026-09-04 updated pcb preview pics
2026-09-06 added prints folder
    [1_PicoDAC_Case_DetachablePart.step, 2_PicoDAC_Case_Main.step, 3_board2_top_case.step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]
